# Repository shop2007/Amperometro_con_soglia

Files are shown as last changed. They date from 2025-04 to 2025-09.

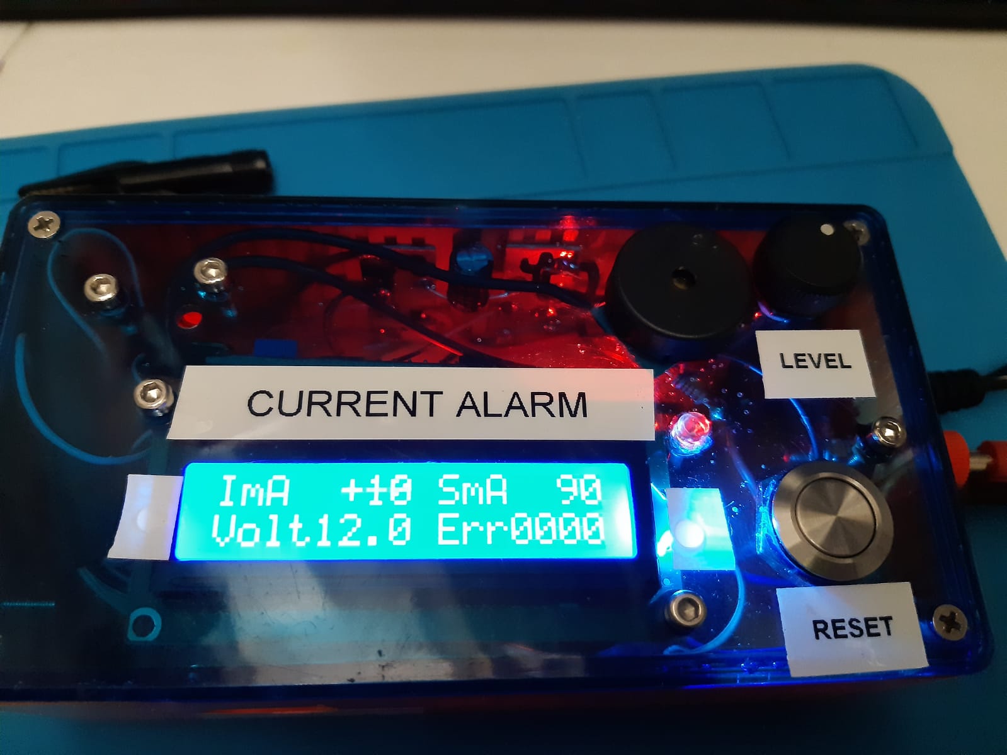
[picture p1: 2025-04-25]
test.jpg

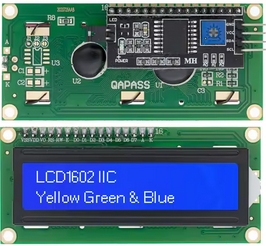
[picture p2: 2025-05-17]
kicad/img/display.jpg

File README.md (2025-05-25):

# Amperometro_con_soglia
Un amperometro galvanicamente isolato con sensore di corrente LEM. Misura la corrente a riposo della batteria auto nel range +/- 1 ampere. Se la corrente supera una soglia impostabile suona il cicalino. Nato per un elettrauto: certe auto moderne si connettono al service a nostra insaputa, e ti trovi la batteria misteriosamente a zero senza saperlo.

# Camper Energy Saver

**Camper Energy Saver** è un sistema elettronico pensato per ottimizzare l'uso dell'energia elettrica a bordo di un camper. Il progetto permette di monitorare in tempo reale corrente e tensione della batteria, proteggere i carichi in caso di sovracorrente, inviare notifiche via SMS e testare l’impianto tramite un menù guidato.

---

## ⚙️ Funzionalità principali

- Lettura di corrente e tensione con sensore LEM
- Gestione soglia corrente per protezione sovraccarichi
- Controllo automatico di un relè di scollegamento carico
- Display LCD I2C 16x2 per visualizzazione locale
- Integrazione con modulo GSM SIM800 per comandi e notifiche SMS
- Comandi remoti: stato, reset, attivazione test, gestione rubrica
- Menu di collaudo guidato (test 1.A, 1.B ecc.)
- Dati persistenti su EEPROM (rubrica, soglie, contatori)
- Watchdog per sicurezza operativa

---

## 🧰 Componenti hardware richiesti

- **Arduino Uno / Nano (ATmega328)**
- **Sensore di corrente LEM** (es. HASS50)
- **Modulo SIM800L GSM**
- **Display LCD 16x2 con interfaccia I2C**
- **Relè 5V**
- **Trimmer** per lettura tensione batteria
- **Resistenze di pull-up/pull-down** dove richiesto
- **Eventuale pulsante** per menu manuale/test
- **Alimentazione 12V camper**

---

## 🖼️ Schema elettrico

<p align="center">
  Schema elettrico
</p>

*(Assicurati che l'immagine sia presente nella cartella `immagini/` del repository.)*

---

## 📸 Foto prototipo montato

<p align="center">
  Montaggio reale
</p>

---

## 🧪 Menù di test e collaudo

Il sistema include un menù test guidato, accessibile da seriale o via SMS:

- **1.A** – Verifica accensione display
- **1.B** – Verifica lettura corrente
- **1.C** – Verifica tensione batteria
- **2.A** – Test attivazione relè
- **2.B** – Verifica invio SMS test

I comandi disponibili via seriale includono:  
`AVANTI`, `RIPETI`, `SALTA`, `ESEGUI`  
oppure selezione diretta con `1.A`, `2.B`, ecc.

---

## 📱 Comandi SMS

| Comando | Descrizione |
|---|---|
| `STATO` | Ricevi stato attuale (corrente, tensione, ecc.) |
| `RESET` | Azzera i contatori di tempo e corrente |
| `TESTRELE` | Attiva il relè per pochi secondi per test |
| `PIN1234` | Autenticazione (sostituire 1234 con il PIN impostato) |
| `HELP` | Elenco comandi disponibili |
| `AGGIUNGI +39xxxxxx`| Aggiunge numero alla rubrica (solo admin) |

---

## 🔧 Installazione

1. **Clona il progetto**:
   ```bash
   git clone https://github.com/shop2007/Camper_energy_saver.git

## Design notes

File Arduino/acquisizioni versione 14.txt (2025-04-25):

Cattura ADC con alimentatore 12 inserito

Corrente nulla nell'anello
Pot A7 = 39 0x27 | Current A2 = 511 0x1FF | Voltage A3 = 0 0x0
Pot A7 = 38 0x26 | Current A2 = 510 0x1FE | Voltage A3 = 0 0x0
Pot A7 = 38 0x26 | Current A2 = 509 0x1FD | Voltage A3 = 0 0x0
Pot A7 = 39 0x27 | Current A2 = 510 0x1FE | Voltage A3 = 0 0x0
Pot A7 = 38 0x26 | Current A2 = 514 0x202 | Voltage A3 = 0 0x0
Pot A7 = 38 0x26 | Current A2 = 512 0x200 | Voltage A3 = 0 0x0
Pot A7 = 38 0x26 | Current A2 = 515 0x203 | Voltage A3 = 0 0x0
Pot A7 = 39 0x27 | Current A2 = 507 0x1FB | Voltage A3 = 0 0x0
Pot A7 = 39 0x27 | Current A2 = 510 0x1FE | Voltage A3 = 0 0x0
Pot A7 = 38 0x26 | Current A2 = 512 0x200 | Voltage A3 = 0 0x0
Pot A7 = 39 0x27 | Current A2 = 511 0x1FF | Voltage A3 = 0 0x0
Pot A7 = 38 0x26 | Current A2 = 511 0x1FF | Voltage A3 = 0 0x0
Pot A7 = 39 0x27 | Current A2 = 514 0x202 | Voltage A3 = 0 0x0
Pot A7 = 39 0x27 | Current A2 = 513 0x201 | Voltage A3 = 0 0x0
Pot A7 = 39 0x27 | Current A2 = 511 0x1FF | Voltage A3 = 0 0x0
Pot A7 = 38 0x26 | Current A2 = 512 0x200 | Voltage A3 = 0 0x0
Pot A7 = 39 0x27 | Current A2 = 515 0x203 | Voltage A3 = 0 0x0
Pot A7 = 39 0x27 | Current A2 = 513 0x201 | Voltage A3 = 0 0x0
Pot A7 = 39 0x27 | Current A2 = 510 0x1FE | Voltage A3 = 0 0x0
Pot A7 = 38 0x26 | Current A2 = 512 0x200 | Voltage A3 = 0 0x0
Pot A7 = 38 0x26 | Current A2 = 511 0x1FF | Voltage A3 = 0 0x0

0,42A 
Pot A7 = 39 0x27 | Current A2 = 615 0x267 | Voltage A3 = 0 0x0
Pot A7 = 39 0x27 | Current A2 = 618 0x26A | Voltage A3 = 0 0x0
Pot A7 = 39 0x27 | Current A2 = 617 0x269 | Voltage A3 = 0 0x0

-0,40A
Pot A7 = 39 0x27 | Current A2 = 409 0x199 | Voltage A3 = 0 0x0
Pot A7 = 38 0x26 | Current A2 = 410 0x19A | Voltage A3 = 0 0x0
Pot A7 = 39 0x27 | Current A2 = 407 0x197 | Voltage A3 = 0 0x0

Volmetro

5,05v  
Pot A7 = 38 0x26 | Current A2 = 513 0x201 | Voltage A3 = 211 0xD3
Pot A7 = 39 0x27 | Current A2 = 509 0x1FD | Voltage A3 = 211 0xD3
Pot A7 = 38 0x26 | Current A2 = 511 0x1FF | Voltage A3 = 211 0xD3

8,94 v
Pot A7 = 38 0x26 | Current A2 = 512 0x200 | Voltage A3 = 392 0x188
Pot A7 = 38 0x26 | Current A2 = 512 0x200 | Voltage A3 = 392 0x188
Pot A7 = 38 0x26 | Current A2 = 511 0x1FF | Voltage A3 = 392 0x188

12.00v
Pot A7 = 38 0x26 | Current A2 = 510 0x1FE | Voltage A3 = 535 0x217
Pot A7 = 38 0x26 | Current A2 = 510 0x1FE | Voltage A3 = 535 0x217
Pot A7 = 38 0x26 | Current A2 = 515 0x203 | Voltage A3 = 535 0x217

15.65v
Pot A7 = 38 0x26 | Current A2 = 512 0x200 | Voltage A3 = 705 0x2C1
Pot A7 = 39 0x27 | Current A2 = 510 0x1FE | Voltage A3 = 705 0x2C1
Pot A7 = 38 0x26 | Current A2 = 509 0x1FD | Voltage A3 = 705 0x2C1

chatgpt
Un adc a 10 bit di arduino nano + rete di attenuazione restituisce i seguenti valori
A 5,05v -> 211 bit (0xD3)
A 8,94v -> 392 bit (0x188)
A 12.00v -> 535 bit (0x217)
A 15.65v -> 705 bit (0x2C1)

Vorrei mi disegnassi una curva teorica del funzionamento, volt-bit

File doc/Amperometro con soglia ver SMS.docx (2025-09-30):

Amperometro con soglia ed allarme sonoro/luminoso/contatto

Versione SMS

V3 30/09/2025

Note importanti:

NON CONNETTERE O DISCONNETTERE IL MODULO SIM CON ALIMENTAZIONE INSERITA. PERICOLO DI DANNEGGIAMENTO DELLA SCHEDA SIM

SE SI ALIMENTA CON BATTERIA ASSICURARE BUON CONTATTO CON I POLI PRIMA DI INSERIRE IL JACK. EVITARE CONTATTI INCERTI. PERICOLO DANNEGGIAMENTO DELLA SCHEDA SIM

MESSA IN FUNZIONE E USO DELLA PARTE SMS.

Firmware installato: GIT\Amperometro_con_soglia\Arduino\amp_sog_19_sms10

- All'avvio il led bianco lampeggia alcune volte velocemente in attesa della SIM.
- Mentre la sim tenta di connettersi alla rete cellulare il suo led rosso e lampeggia velocemente.
- Quando è connessa lampeggia una volta ogni tre secondi.
- Quando manda un sms o lo riceve, accende il led bianco

Comandi da inviare via SMS da qualsiasi telefono (attenzione alle Maiuscole-Minuscole).

- “User1 +393332108888” - mette il numero ricevuto come utente 1 da avvisare su allarmi Aggiungere ai numeri il +39 . User1 riceve SMS di risposta "Utente1 registrato correttamente"
- “User2 +393332109999” - mette il numero ricevuto come utente 2 da avvisare su allarmi Aggiungere ai numeri il +39 . User2 riceve SMS di risposta "Utente2 registrato correttamente"
- Statoattuale - Riceve un SMS con i valori sul display in quel momento
- Resetsystem - resetta da remoto il sistema e il conta allarmi
- DeleteUtente2 - resta attivo solo “User1”, che riceve SMS di risposta "Utente 2 cancellato"

Se la sim è connessa blinka ogni 3 secondi, anche se non c’è credito o sms disponibili

In caso di allarme per soglia superata verrà inviato solo il primo SMS.

Se si stacca l’interruttore della SIM, quando si riconnette occorre premere il tasto RESET per essere sicuri che la SIM si ricolleghi correttamente (verificare lampeggio ogni 3 secondi)

Caratteristiche del sensore LEM.

- Corrente (cavo passante nell’anello)
  - Range +/- 1500 mA DC (corrente continua)
  - Risoluzione +/-4 mA (LSB dell’ADC a 10 bit di Arduino)
  - Precisione 3%
- Tensione di batteria, Banana rossa (+) e Nera (-)
  - Range da 3 a 22 Volt DC
  - Risoluzione 0.1 Volt
  - Precisione +/- 0.1 Volt
- Soglia Allarme sonoro (potenziometro)
  - Range da 1 a 1000 mA
  - Vale per entrambe le polarità della corrente
- Conteggio superamento soglia di corrente
  - Range da 1 a 9999 secondi
  - Precisione 1mA
  - Resettabile continuamente con pulsante
- Allarmi soglia superata
  - Visivo (Led bianco)
  - Acustico (Cicalino, escludibile se al reset si tiene premuto il pulsante di azzeramento per alcuni secondi)
  - Uscita relay (su mammut), contatto chiuso per soglia superata

Note:

- Scritte su display:
  - Ima +18 = corrente in mA letta dal sensore ad anello, bipolare con segno
  - SmA 912 = Soglia in mA del livello da superare per avere allarme
  - Volt 11.9 = tensione rilevata sulle banane rossa/nera – Unipolare senza segno
  - Err 0000 = conteggio secondi in cui la corrente ha superato la soglia
- LEVEL = potenziometro per regolare la soglia SmA
- RESET = pulsante di azzeramento conteggio secondi superamento soglia
- LED BIANCO = segnala soglia superata

Alimentare con alimentatore esterno 12v

La presa USB C serve solo per aggiornamento firmware

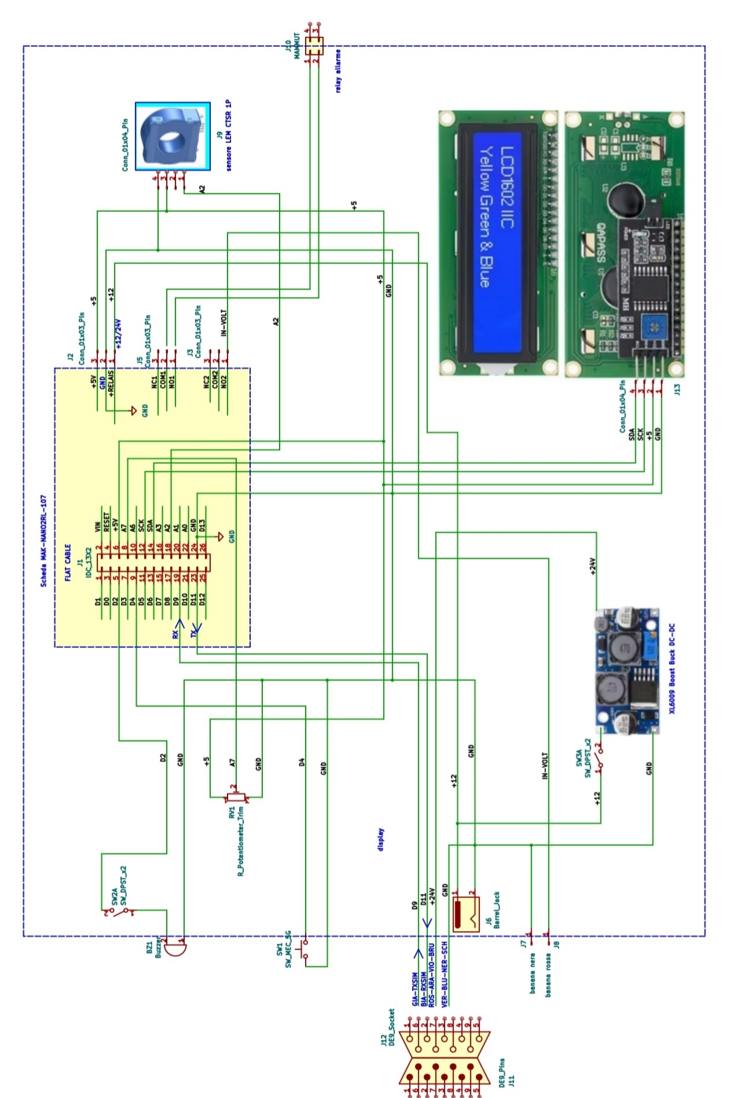
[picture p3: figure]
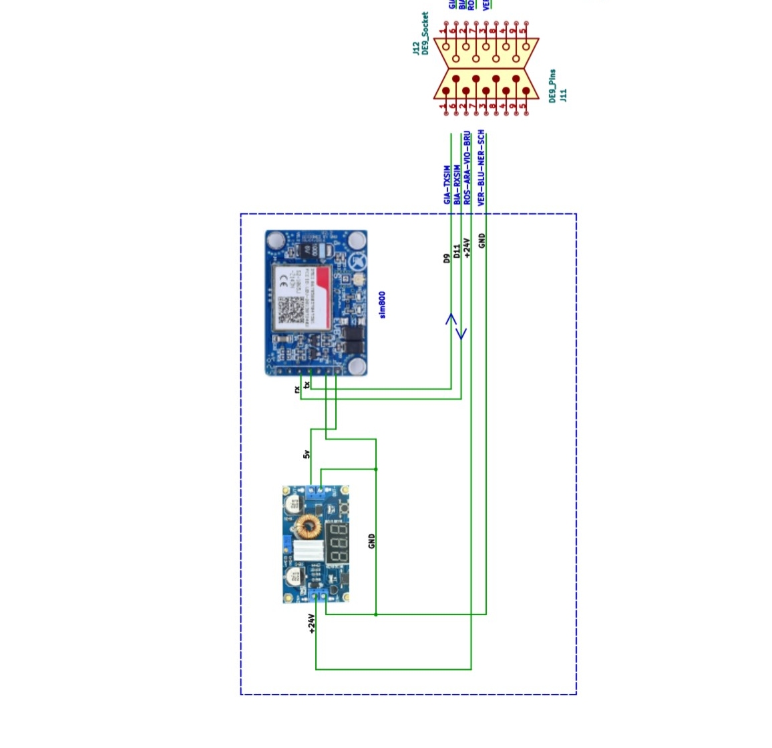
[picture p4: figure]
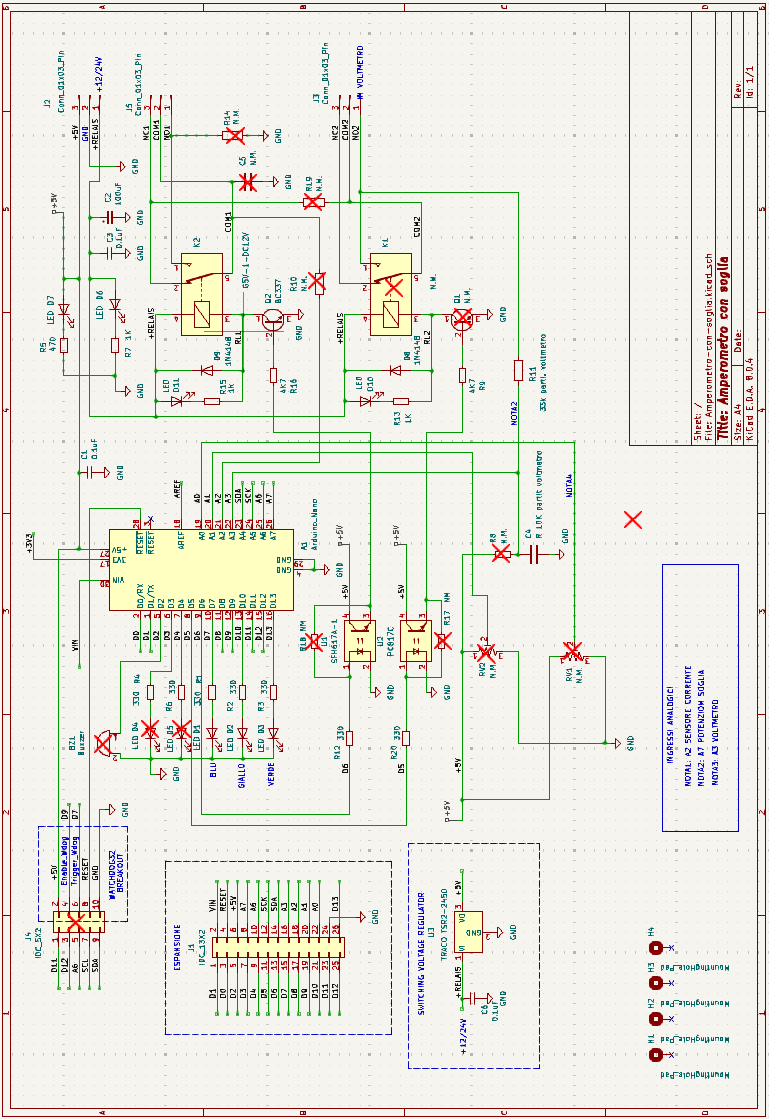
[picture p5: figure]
Immagine che contiene testo, diagramma, Piano, schematico Il contenuto generato dall'IA potrebbe non essere corretto.

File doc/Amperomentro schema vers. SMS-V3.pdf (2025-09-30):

# Amperometro con soglia ed allarme sonoro/luminoso/contatto Versione SMS

V3 30/09/2025

# Note importanti: NON CONNETTERE O DISCONNETTERE IL MODULO SIM CON ALIMENTAZIONE INSERITA. PERICOLO DI DANNEGGIAMENTO DELLA SCHEDA SIM SE SI ALIMENTA CON BATTERIA ASSICURARE BUON CONTATTO CON I POLI PRIMA DI INSERIRE IL JACK. EVITARE CONTATTI INCERTI. PERICOLO DANNEGGIAMENTO DELLA SCHEDA SIM

MESSA IN FUNZIONE E USO DELLA PARTE SMS.
Firmware installato: GIT\Amperometro_con_soglia\Arduino\amp_sog_19_sms10
- All'avvio il led bianco lampeggia alcune volte velocemente in attesa della SIM.
- Mentre la sim tenta di connettersi alla rete cellulare il suo led rosso e lampeggia velocemente.
- Quando è connessa lampeggia una volta ogni tre secondi.
- Quando manda un sms o lo riceve, accende il led bianco

Comandi da inviare via SMS da qualsiasi telefono (attenzione alle Maiuscole-Minuscole).
- “User1 +393332108888” - mette il numero ricevuto come utente 1 da avvisare su allarmi Aggiungere ai numeri il +39 . User1 riceve SMS di risposta "Utente1 registrato correttamente"
- “User2 +393332109999” - mette il numero ricevuto come utente 2 da avvisare su allarmi Aggiungere ai numeri il +39 . User2 riceve SMS di risposta "Utente2 registrato correttamente"
- Statoattuale - Riceve un SMS con i valori sul display in quel momento
- Resetsystem - resetta da remoto il sistema e il conta allarmi
- DeleteUtente2 - resta attivo solo “User1”, che riceve SMS di risposta "Utente 2 cancellato"

Se la sim è connessa blinka ogni 3 secondi, anche se non c’è credito o sms disponibili
In caso di allarme per soglia superata verrà inviato solo il primo SMS.
Se si stacca l’interruttore della SIM, quando si riconnette occorre premere il tasto RESET per essere sicuri che la SIM si ricolleghi correttamente (verificare lampeggio ogni 3 secondi)

Caratteristiche del sensore LEM.
- Corrente (cavo passante nell’anello)
o Range +/- 1500 mA DC (corrente continua)
o Risoluzione +/-4 mA (LSB dell’ADC a 10 bit di Arduino) o Precisione 3%
- Tensione di batteria, Banana rossa (+) e Nera (-)
o Range da 3 a 22 Volt DC
o Risoluzione 0.1 Volt
o Precisione +/- 0.1 Volt
- Soglia Allarme sonoro (potenziometro)
o Range da 1 a 1000 mA
o Vale per entrambe le polarità della corrente
- Conteggio superamento soglia di corrente
o Range da 1 a 9999 secondi
o Precisione 1mA
o Resettabile continuamente con pulsante
- Allarmi soglia superata
o Visivo (Led bianco)
o Acustico (Cicalino, escludibile se al reset si tiene premuto il pulsante di azzeramento per alcuni secondi)
o Uscita relay (su mammut), contatto chiuso per soglia superata

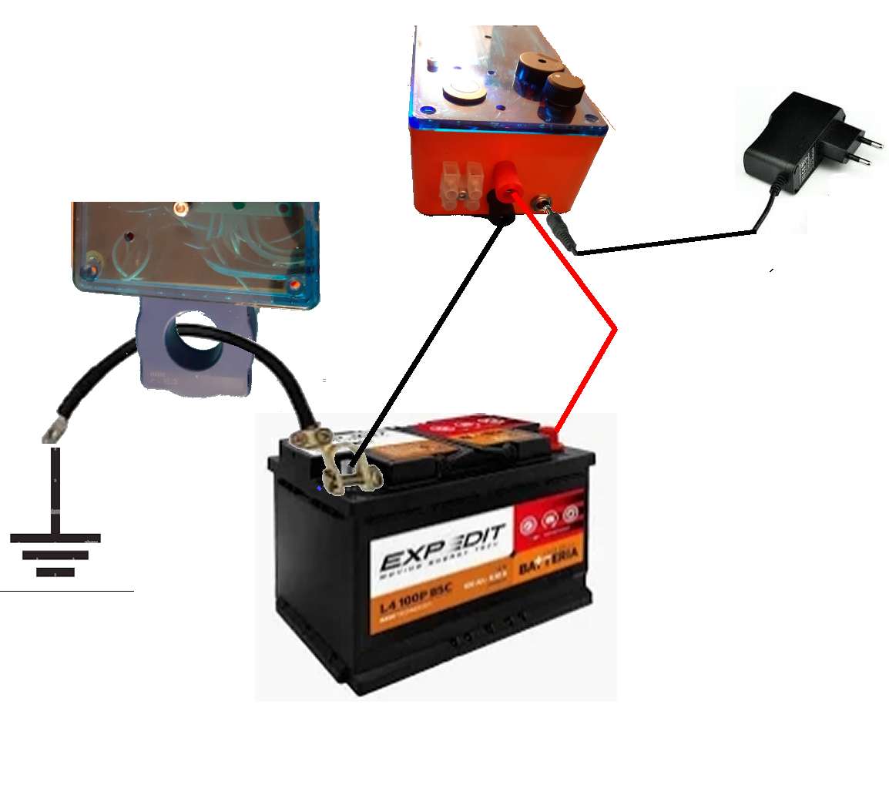
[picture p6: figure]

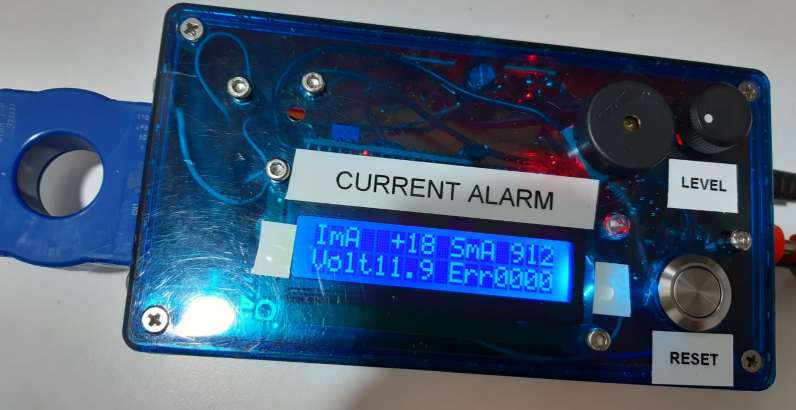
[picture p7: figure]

Note:
- Scritte su display:
o Ima +18 = corrente in mA letta dal sensore ad anello, bipolare con segno
o SmA 912 = Soglia in mA del livello da superare per avere allarme
o Volt 11.9 = tensione rilevata sulle banane rossa/nera – Unipolare senza segno o Err 0000 = conteggio secondi in cui la corrente ha superato la soglia
- LEVEL = potenziometro per regolare la soglia SmA
- RESET = pulsante di azzeramento conteggio secondi superamento soglia
- LED BIANCO = segnala soglia superata

Alimentare con alimentatore esterno 12v
La presa USB C serve solo per aggiornamento firmware


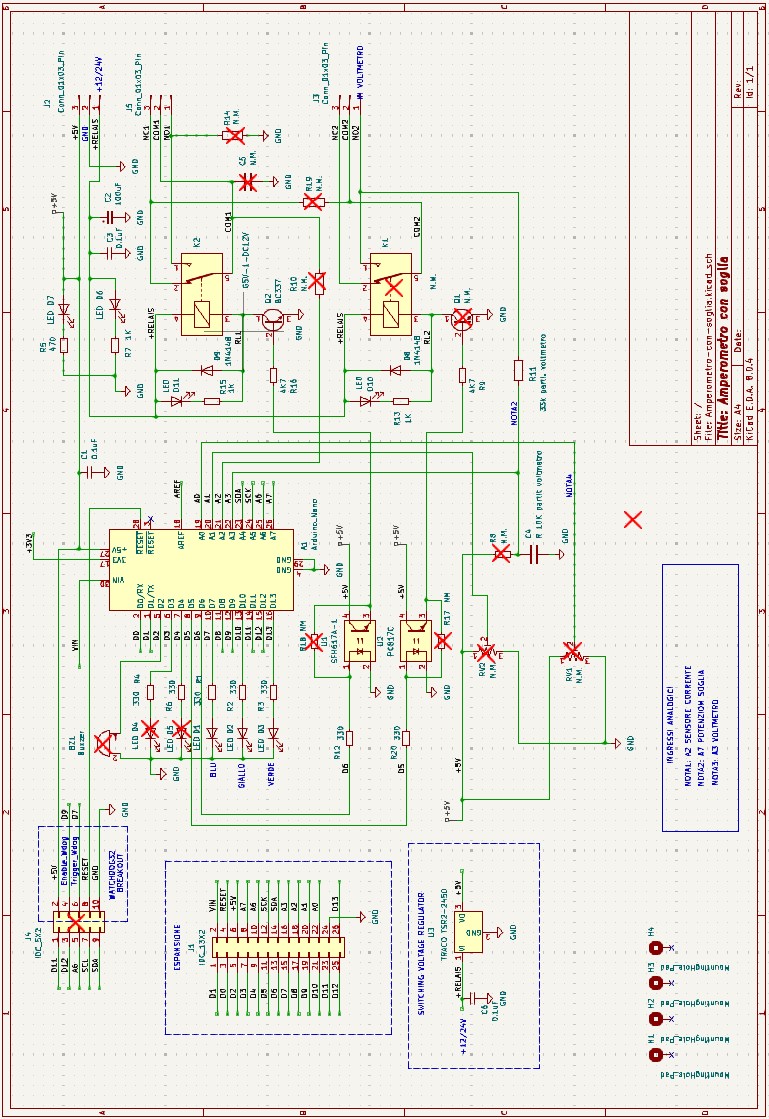
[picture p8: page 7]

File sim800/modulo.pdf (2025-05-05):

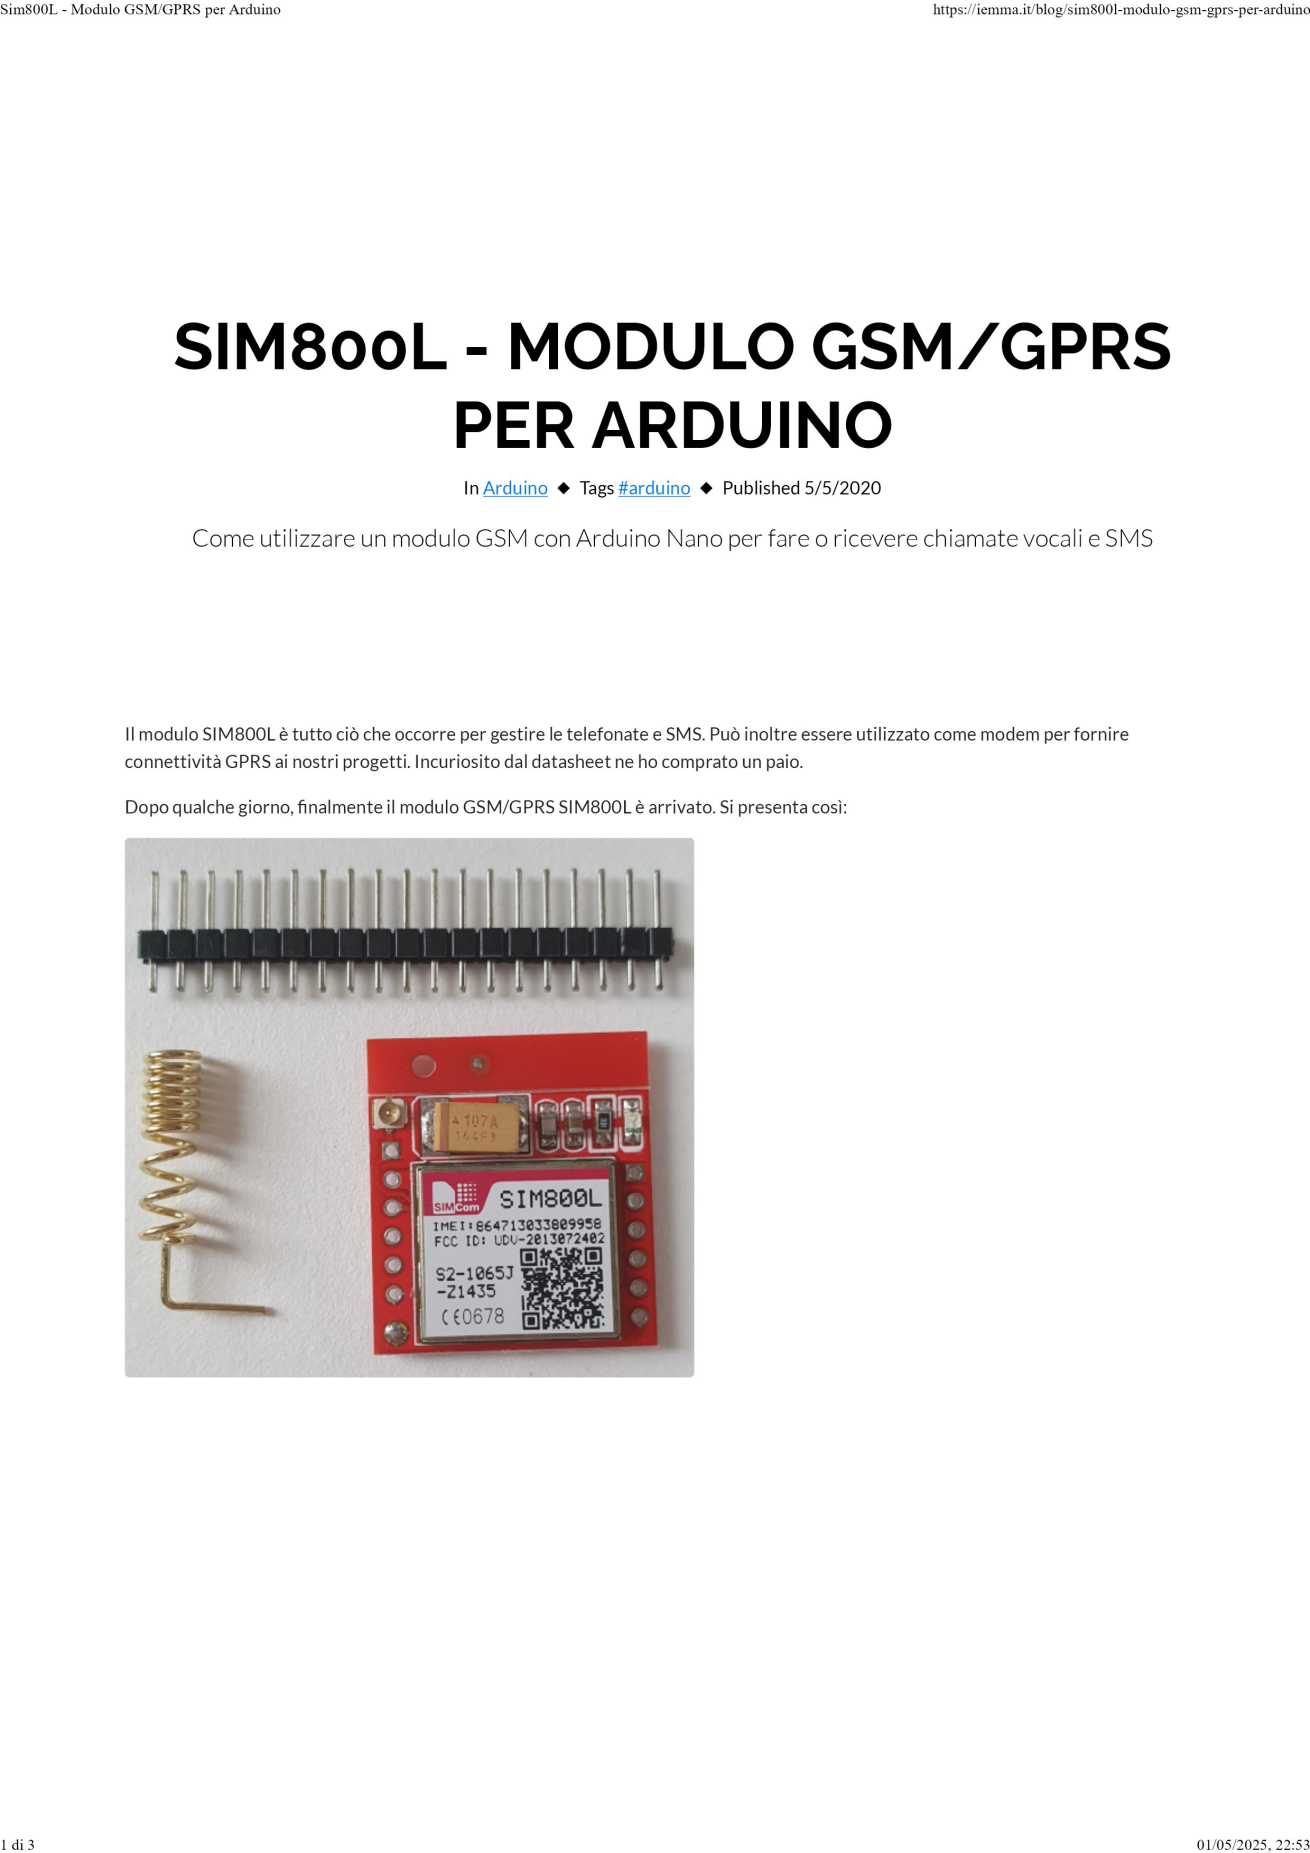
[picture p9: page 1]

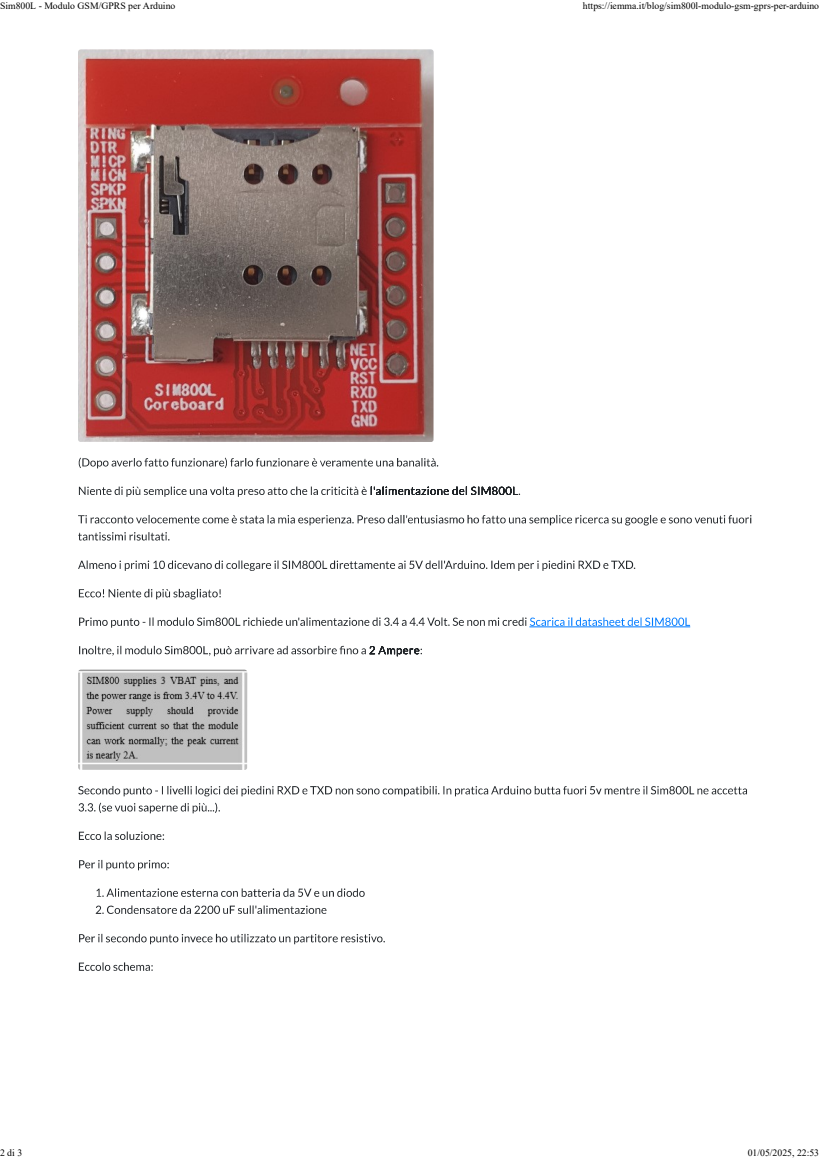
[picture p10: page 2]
Sim800L - Modulo GSM/GPRS per Arduino; https://iemma.it/blog/sim800l-modulo-gsm-gprs-per-arduino

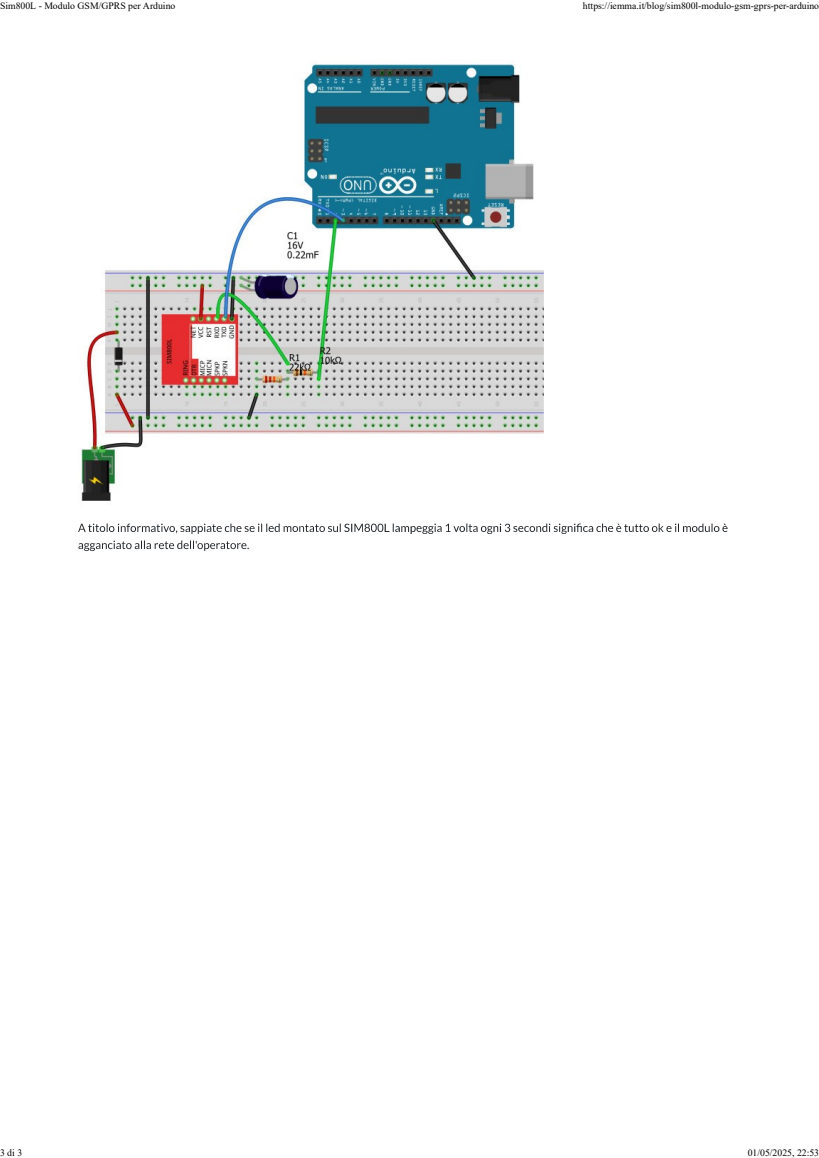
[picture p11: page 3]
Sim800L - Modulo GSM/GPRS per Arduino; https://iemma.it/blog/sim800l-modulo-gsm-gprs-per-arduino

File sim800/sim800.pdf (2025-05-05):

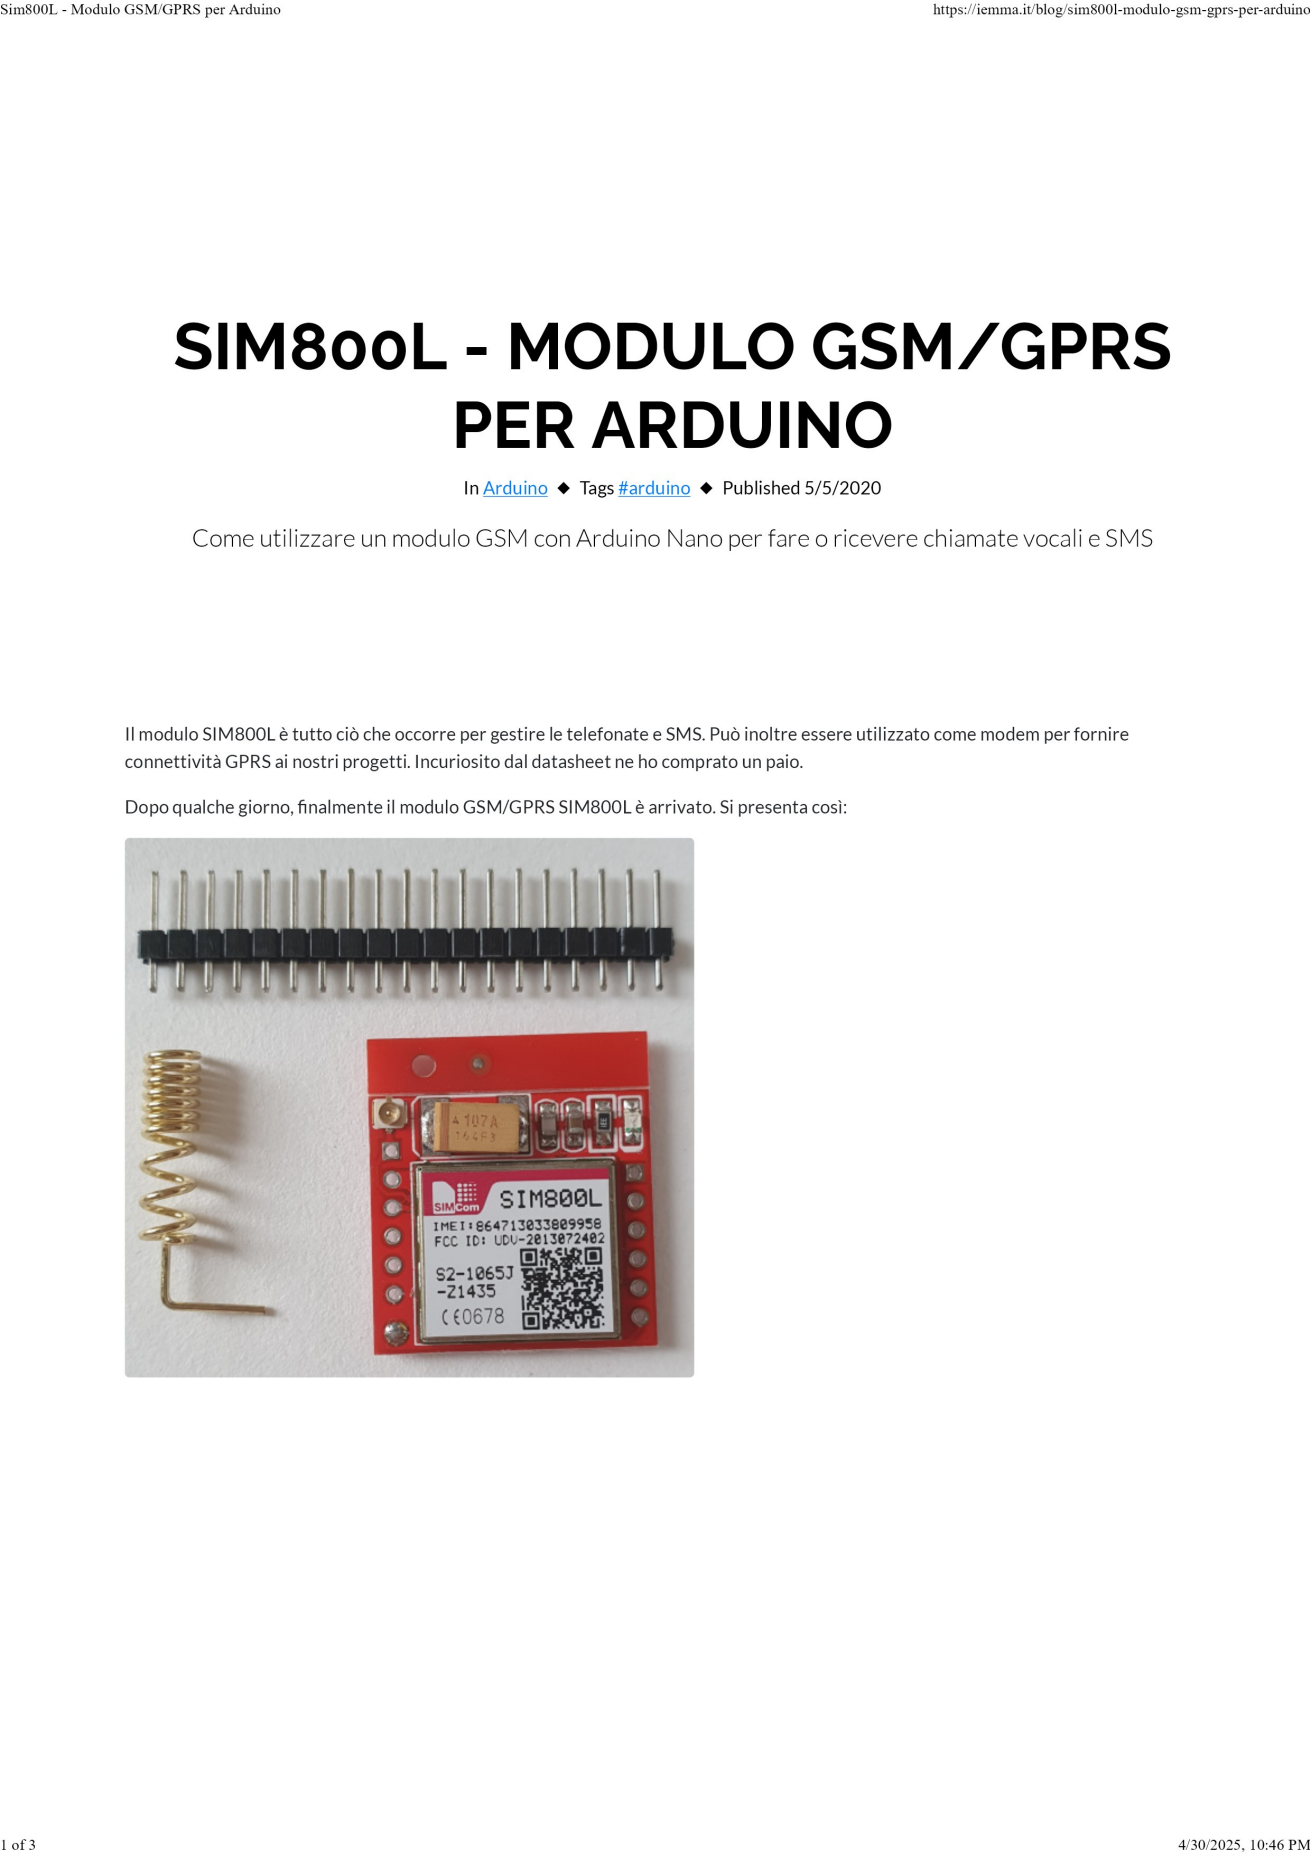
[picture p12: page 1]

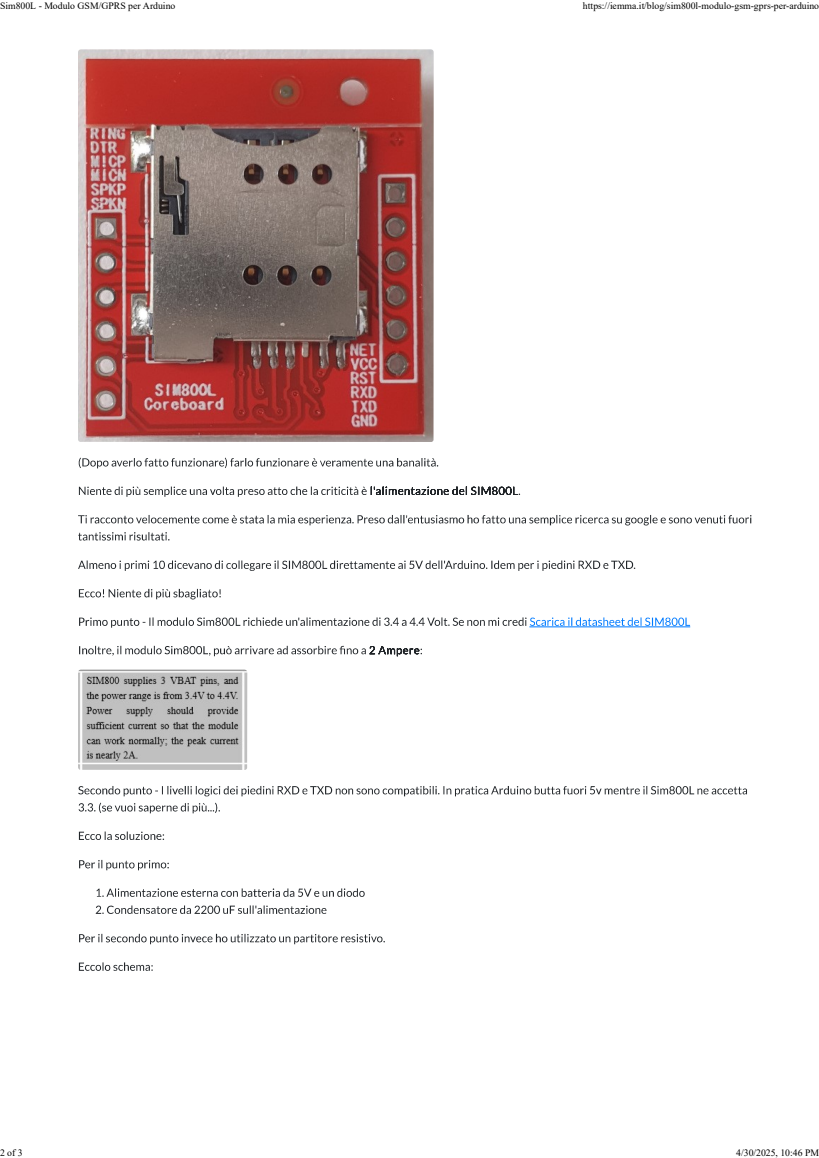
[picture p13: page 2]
Sim800L - Modulo GSM/GPRS per Arduino; https://iemma.it/blog/sim800l-modulo-gsm-gprs-per-arduino

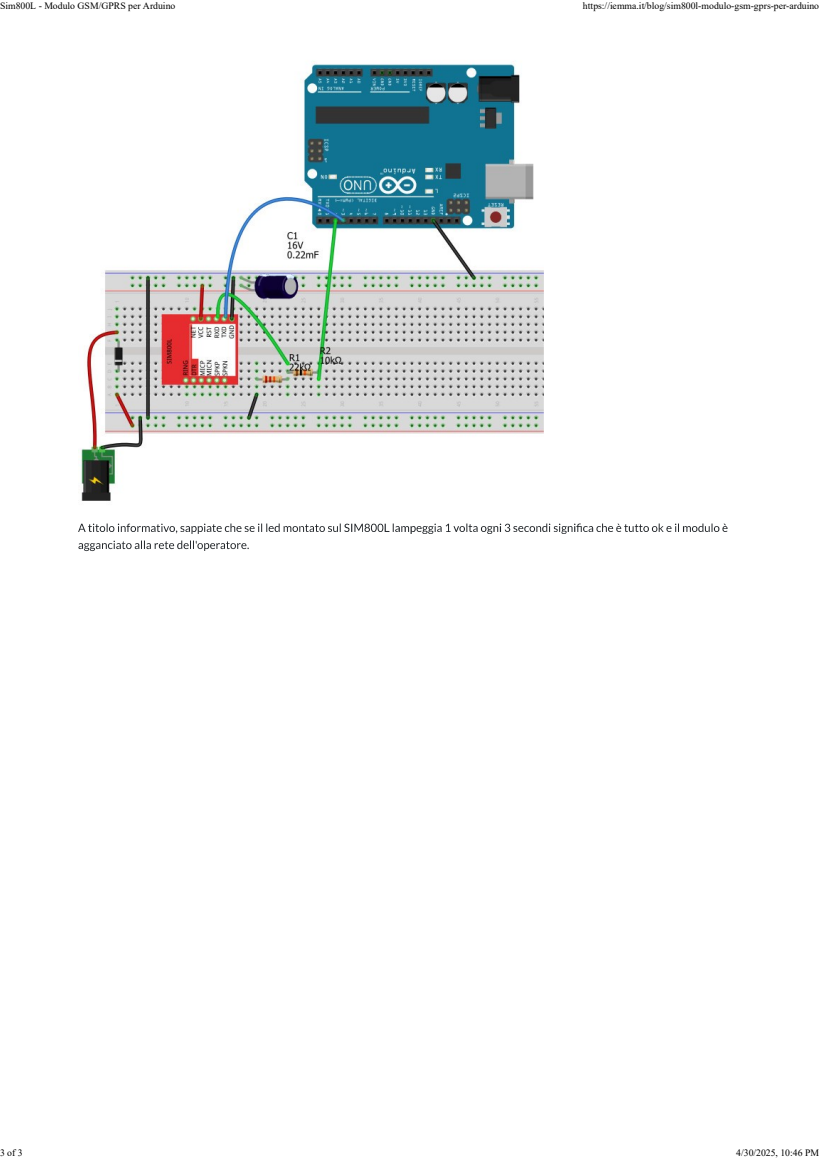
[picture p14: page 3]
Sim800L - Modulo GSM/GPRS per Arduino; https://iemma.it/blog/sim800l-modulo-gsm-gprs-per-arduino

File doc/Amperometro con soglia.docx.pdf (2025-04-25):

# Amperometro con soglia ed allarme sonoro/luminoso/contatto

V1 19/02/2025
Caratteristiche.
- Corrente (cavo passante nell’anello)
o Range +/- 1500 mA DC (corrente continua)
o Risoluzione +/-4 mA (LSB dell’ADC a 10 bit di Arduino) o Precisione 3%
- Tensione di batteria, Banana rossa (+) e Nera (-)
o Range da 3 a 22 Volt DC
o Risoluzione 0.1 Volt
o Precisione +/- 0.1 Volt
- Soglia Allarme sonoro (potenziometro)
o Range da 1 a 1000 mA
o Vale per entrambe le polarità della corrente
- Conteggio superamento soglia di corrente
o Range da 1 a 9999 secondi
o Precisione 1mA
o Resettabile continuamente con pulsante
- Allarmi soglia superata
o Visivo (Led bianco)
o Acustico (Cicalino, escludibile se al reset si tiene premuto il pulsante di azzeramento per alcuni secondi)
o Uscita relay (su mammut), contatto chiuso per soglia superata

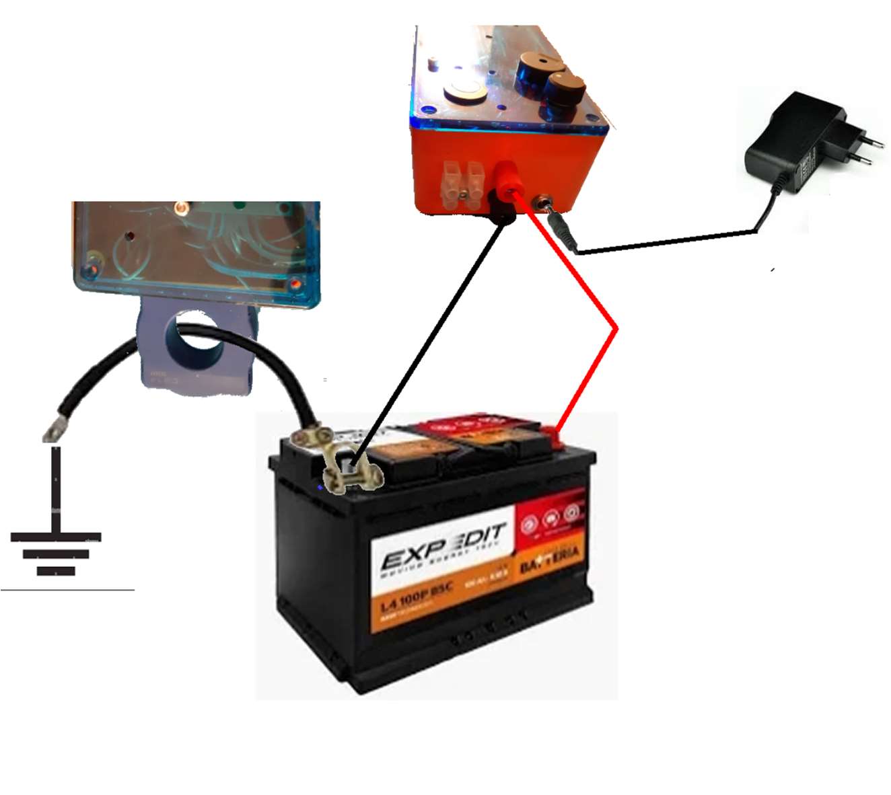
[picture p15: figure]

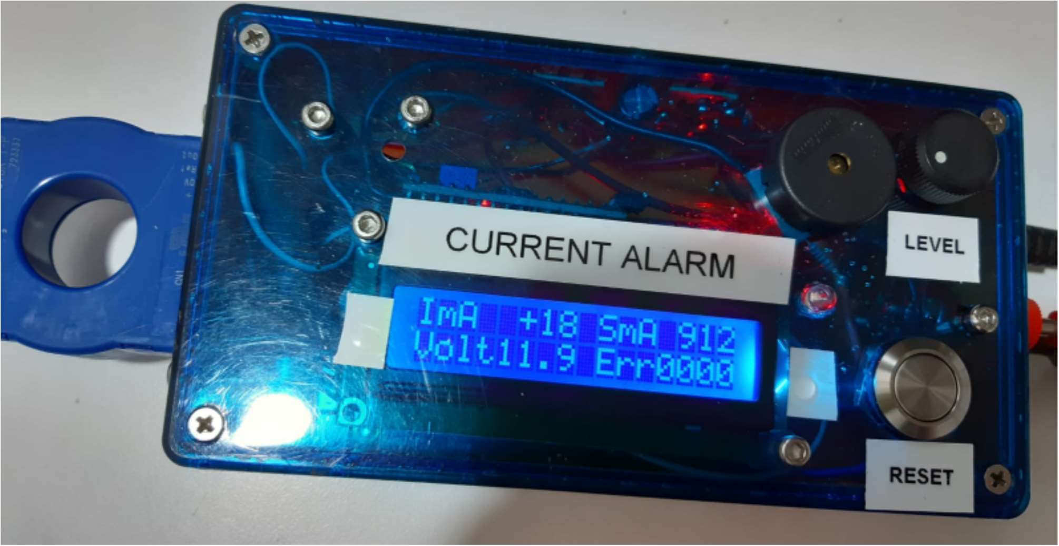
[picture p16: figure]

Note:
- Scritte su display:
o Ima +18 = corrente in mA letta dal sensore ad anello, bipolare con segno
o SmA 912 = Soglia in mA del livello da superare per avere allarme
o Volt 11.9 = tensione rilevata sulle banane rossa/nera – Unipolare senza segno o Err 0000 = conteggio secondi in cui la corrente ha superato la soglia
- LEVEL = potenziometro per regolare la soglia SmA
- RESET = pulsante di azzeramento conteggio secondi superamento soglia
- LED BIANCO = segnala soglia superata
Alimentare con alimentatore esterno 12v
La presa USB C serve solo per aggiornamento firmware

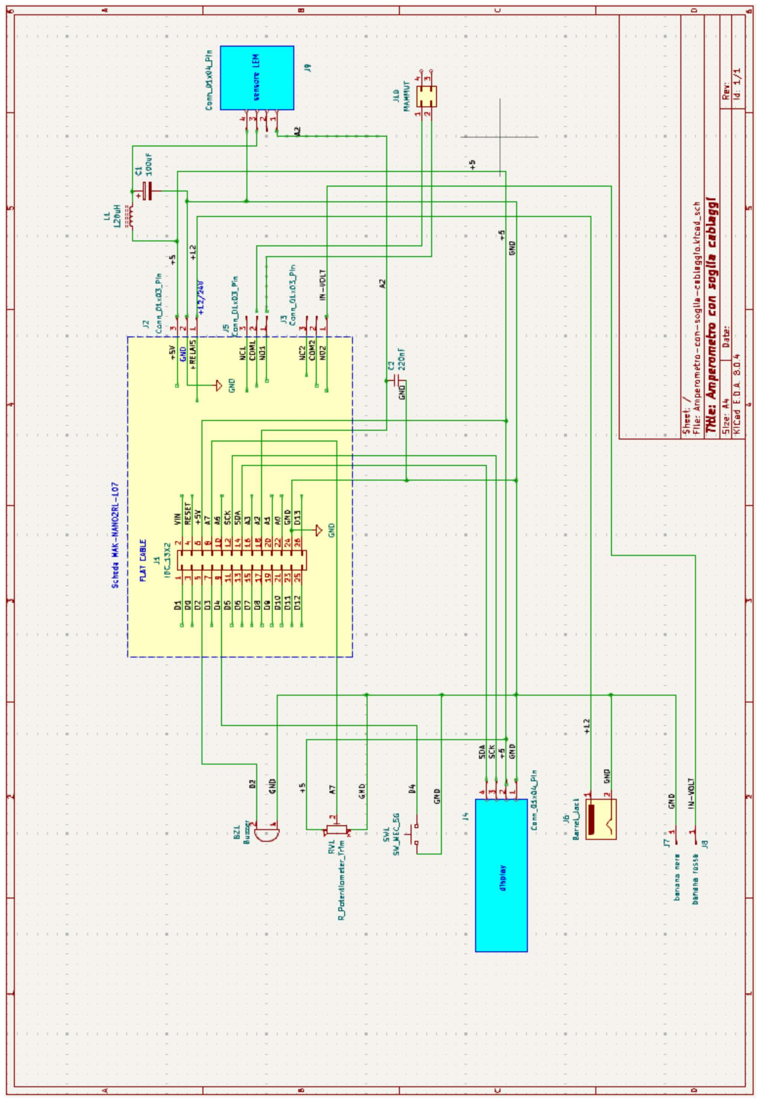
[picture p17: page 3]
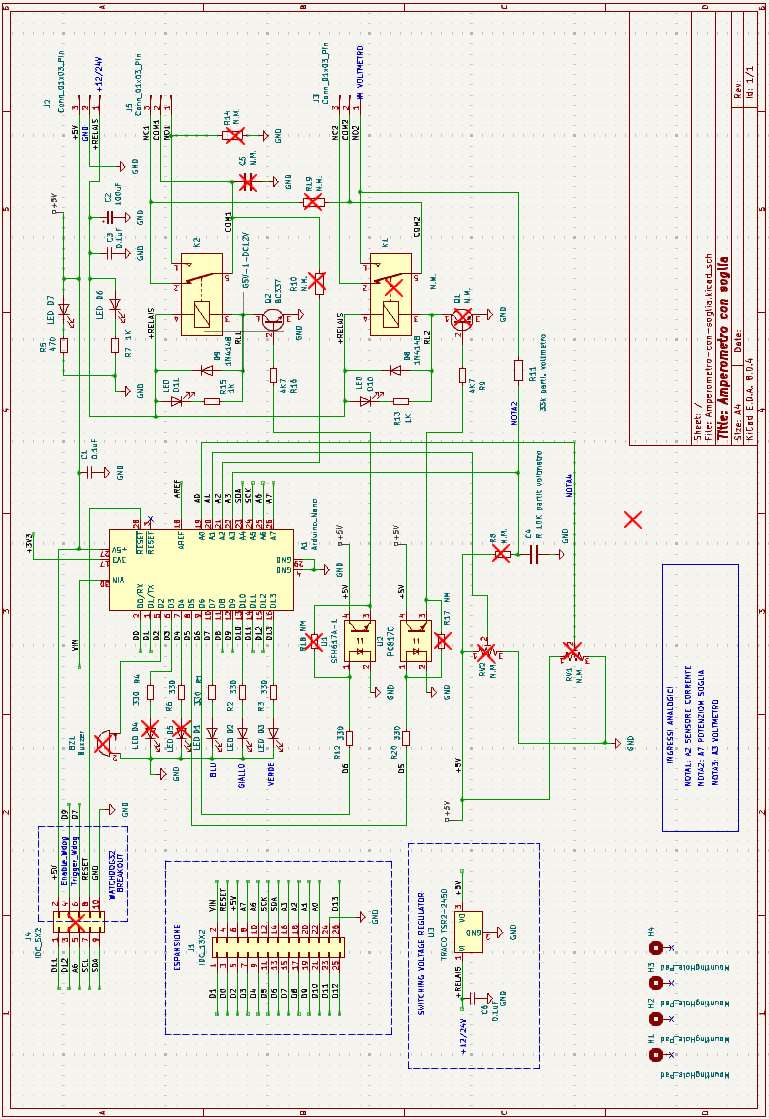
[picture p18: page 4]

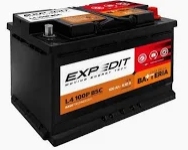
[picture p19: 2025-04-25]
doc/pic/batt1.jpg

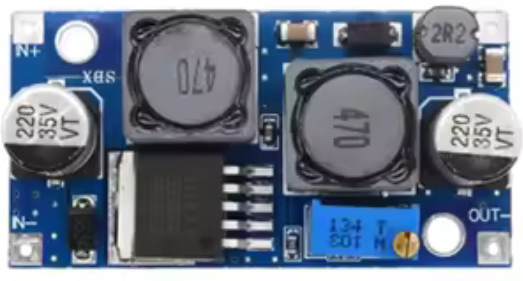
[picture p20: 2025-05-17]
kicad/img/XL6009.png

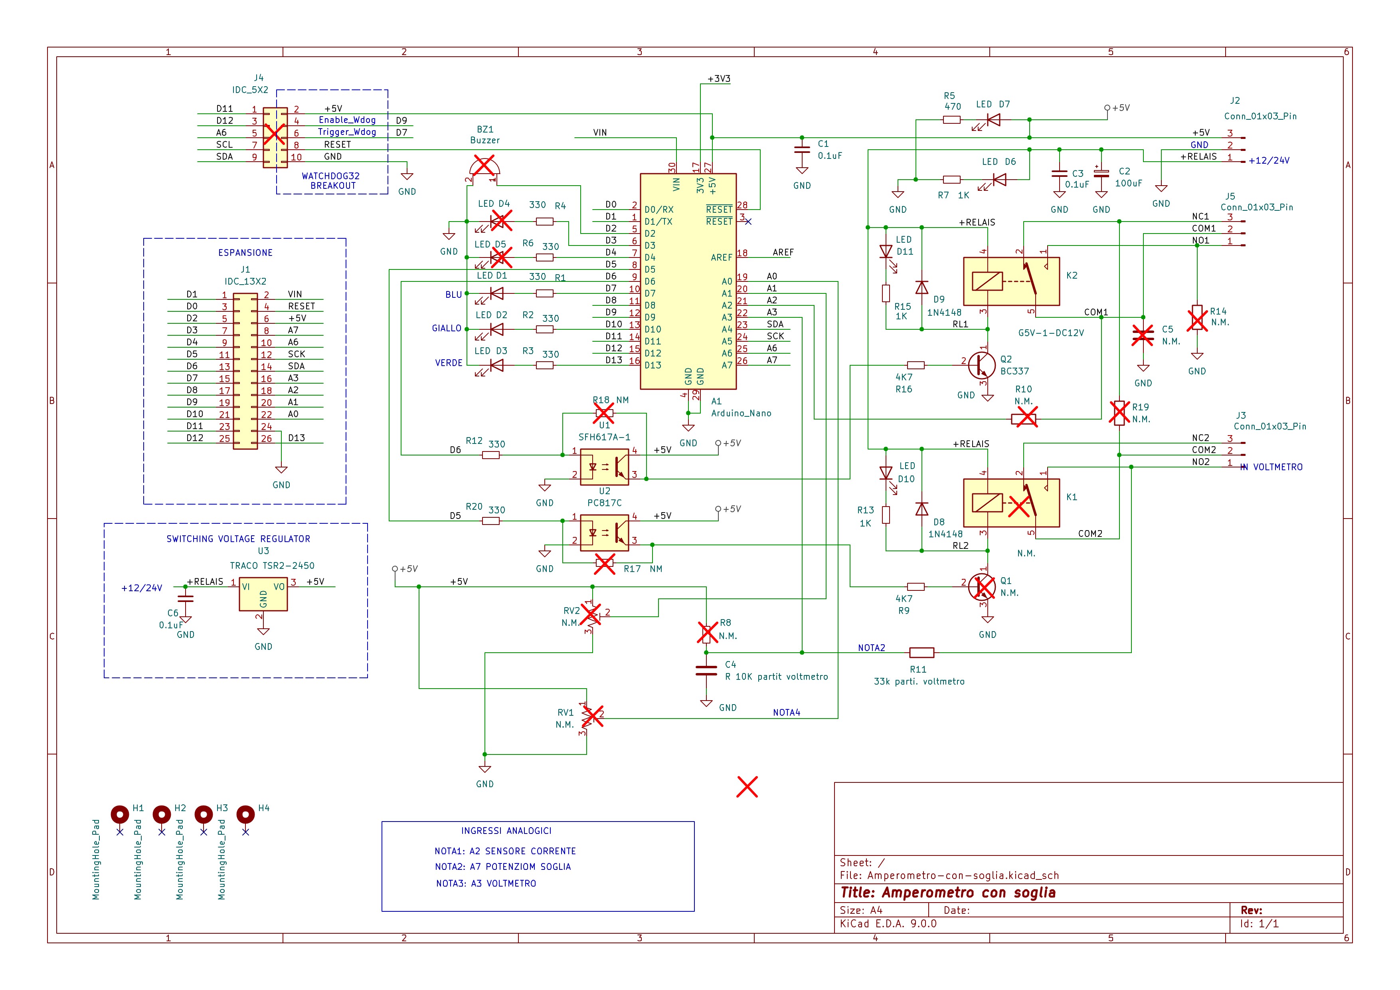
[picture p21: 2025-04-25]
doc/pic/schema01.jpg

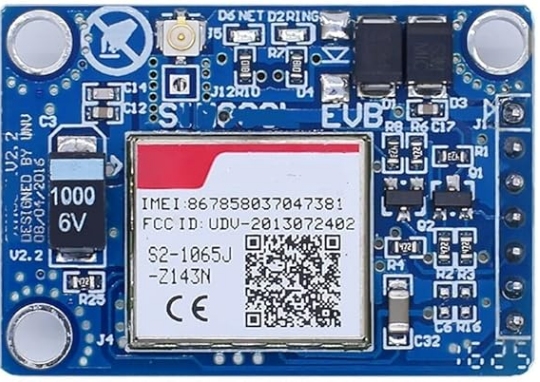
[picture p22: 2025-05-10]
sim800.jpg

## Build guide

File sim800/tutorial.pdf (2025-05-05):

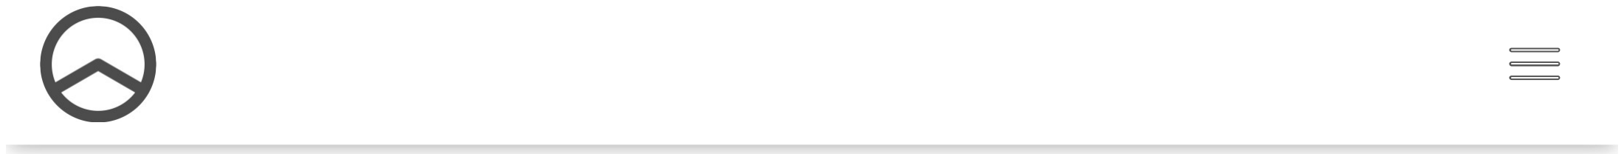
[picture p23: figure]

## Guida completa modulo GSM SIM800L

Pubblicato da Alessandro il 02/01/2023

# Introduzione

Confesso che non è la prima volta che progetto un dispositivo che integra questo modulo di comunicazione GSM. Tuttavia, in passato, mi sono sempre arenato senza riuscire a farlo funzionare.

Stavolta ho passato molte ore a studiare e a fare prove fino a quando non ho finalmente ottenuto il risultato sperato. Dalla lettura dei forum ho notato che non poche persone hanno avuto i miei stessi problemi. Ecco perché ho deciso di condividere l’esito delle mie tante ricerche e dei vari esperimenti (molti dei quali falliti).

Spero che questa guida aiuti molti maker appassionati di elettronica a risolvere gli stessi problemi e a realizzare i loro progetti.

Cliccando sul tag SIM800L potrete scoprire tutti gli articoli e i progetti in cui abbiamo utilizzato questo componente.

# Componenti

Guida completa modulo GSM SIM800L - officinasottocasa | https://www.officinasottocasa.it/gsm-sim800l/
1 di 17 | 01/05/2025, 22:47

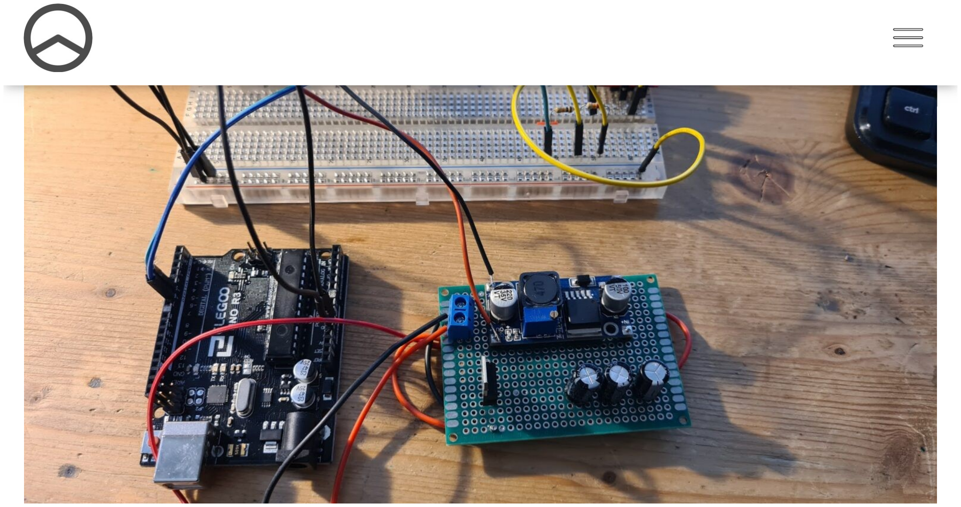
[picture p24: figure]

Iniziamo come sempre nei nostri articoli con il materiale utilizzato nel progetto:

.Una CPU Arduino UNO R3 (versione cinese con interfaccia CH340) per gestire l’interfaccia con il PC: guarda l’articolo su amazon
Uno step-down DC-DC con integrato LM2596: guarda l’articolo su amazon Un modulo GSM SIM800L: guarda l’articolo su amazon
Una resistenza da 10K e una da 22K;
Condensatori vari messi in parallelo.

(In qualità di Affiliato Amazon io ricevo un guadagno dagli acquisti idonei)

# Alimentazione

Iniziamo con una tabella che riporta l’assorbimento (in mA e A) del modulo per ogni specifica

Prototipo con breadbord per SIM800L e UNO R3

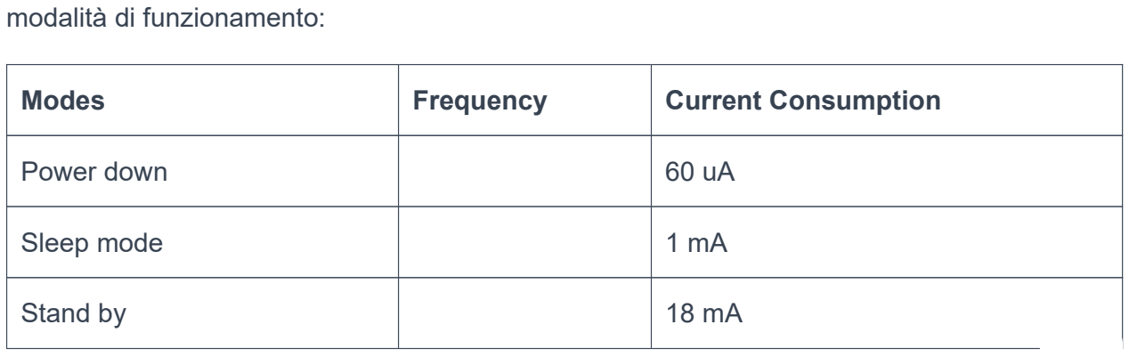
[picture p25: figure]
modalità di funzionamento:; Modes; Frequency; Current Consumption; Power down; Sleep mode; Stand by

2 di 17 | 01/05/2025, 22:47

Call | GSM850 | 199 mA
Call | EGSM900 | 216 mA
Call | DCS1800 | 146 mA
Call | PCS1900 | 131 mA
GPRS | | 453 mA
Transmission burst | | 2 A

Tabella degli assorbimenti per modalità di funzionamento
L’intervallo di tensione per l’alimentazione di questo modulo va dai 3.4V ai 4.4V. Per questo motivo, nel mio precedente articolo sull’allarme GSM per il livello di carica della batteria della moto (https://www.officinasottocasa.it/allarme-gsm-per-batteria-scarica-progettohardware/), avevo pensato di alimentare il modulo con un semplice partitore di tensione in uscita dall’integrato LM7805.

Guardando la tabella della corrente necessaria per il funzionamento delle varie modalità appare evidente che, contrariamente a quanto pensassi (e avessi visto in qualche articolo su internet), non è assolutamente possibile alimentare il modulo in questo modo. Tanto meno utilizzando direttamente la porta 5V di Arduino.

In rete ho visto alcuni “colleghi” che hanno utilizzato una batteria LIPO da 3.7V. Effettivamente sarebbe stato possibile. Ma per l’applicazione in dispositivi permanentemente connessi avremmo dovuto sviluppare anche la gestione della carica della stessa batteria, magari con un BMS per batterie LIPO.

Ho preferito la soluzione dello step-down DC-DC che trova facile impiego sia per applicazione su banco prova che nel mio progetto originario da cui nasce l’esigenza del suo utilizzo.

Visto che tornerà utile spesso, mi sono costruito (su una basetta mille-fori) un mini modulo di alimentazione permanente composto da un banale LM7805 (che, lo ricordiamo, è uno step-down DC-DC con uscita fissa a 5V) per alimentare qualunque scheda Arduino e uno step-down DC-DC con uscita variabile che utilizza un LM2596, in grado di supportare correnti molto più elevate.

Attenzione: i condensatori che vedete in foto non sono collegati al circuito.

3 di 17 | 01/05/2025, 22:47

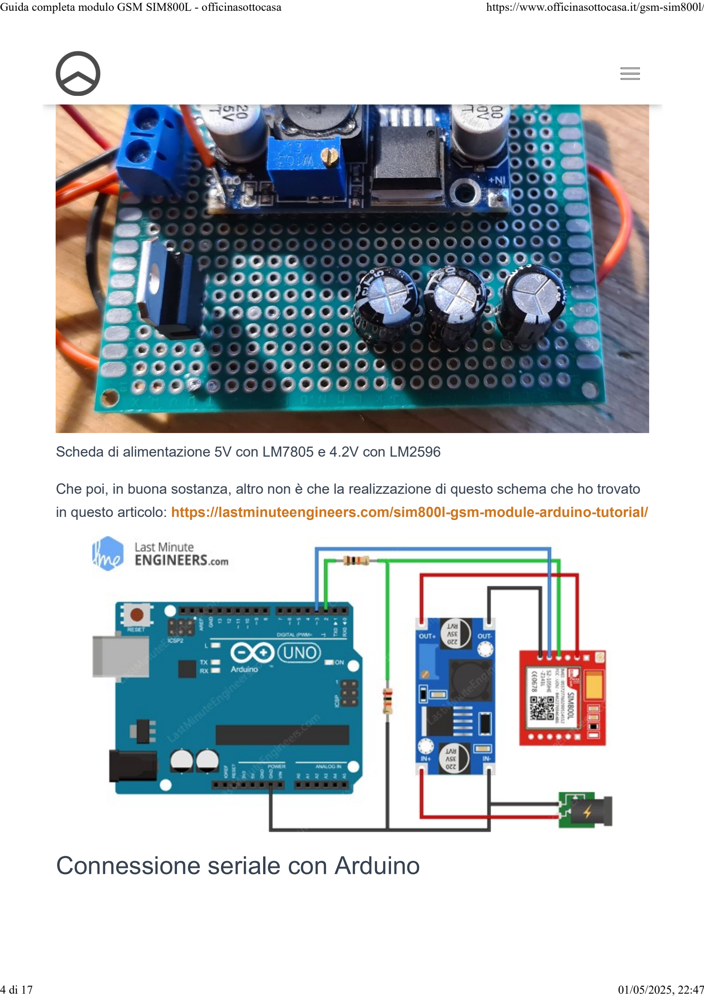
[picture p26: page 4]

Che poi, in buona sostanza, altro non è che la realizzazione di questo schema che ho trovato in questo articolo: https://lastminuteengineers.com/sim800l-gsm-module-arduino-tutorial/

# Connessione seriale con Arduino

Scheda di alimentazione 5V con LM7805 e 4.2V con LM2596

4 di 17 | 01/05/2025, 22:47

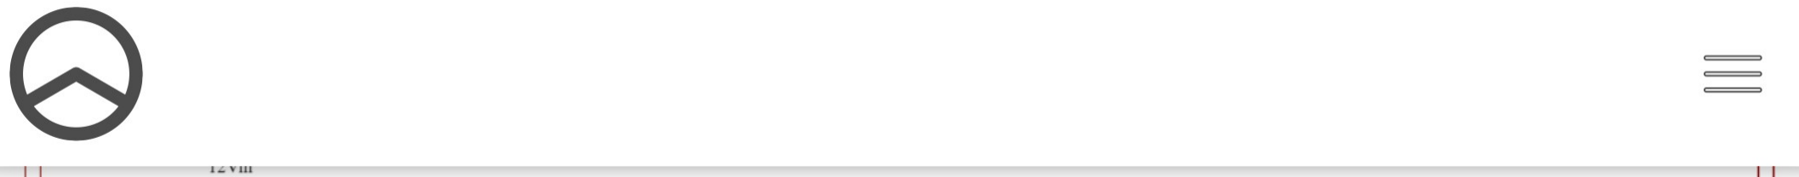
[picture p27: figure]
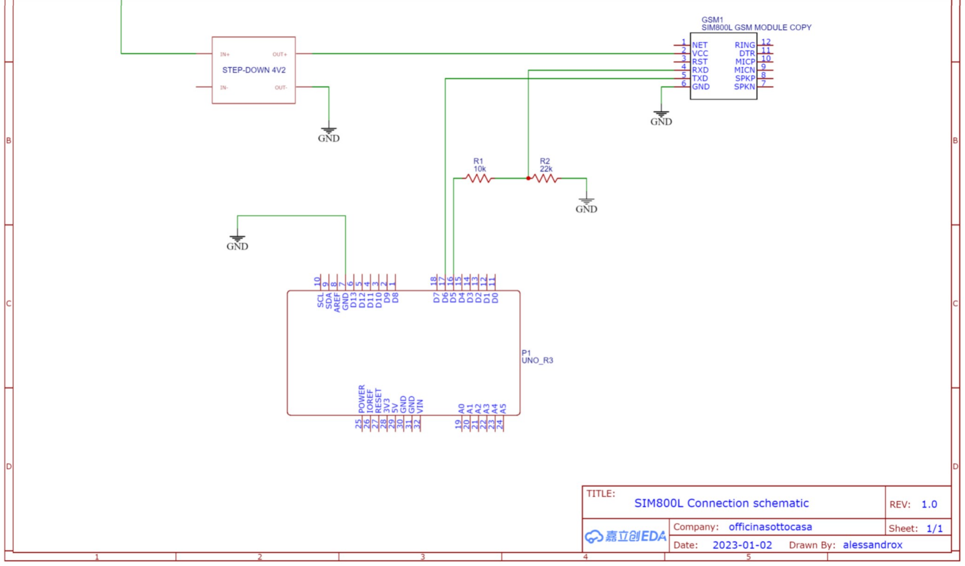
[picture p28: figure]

Iniziamo con una piccola nota sulla scheda Elegoo UNO R3, clone della omologa Arduino UNO R3.

Ha lo stesso integrato dell’originale Arduino ATMEGA328P. Tuttavia, il convertitore USB – Seriale utilizza i chip CH340G e i driver per questo Chip non sono compresi nell’installazione dell’IDE di Arduino. Motivo per cui dovranno essere installati separatamente. In questo articolo https://www.makerslab.it/installare-i-driver-per-il-modulo-ftdi-ch340g-per-i-cloni-diarduino/ trovate le informazioni e i link per scaricare e installare i driver per il CH340G.

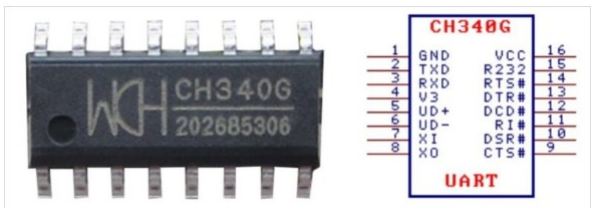
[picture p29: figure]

A questo punto dobbiamo aprire un inciso sui livelli logici che non sono gli stessi tra la scheda

Schema di connessione SIM800L e Arduino UNO R3

Convertitore USB-Seriale cloni Arduino

5 di 17 | 01/05/2025, 22:47

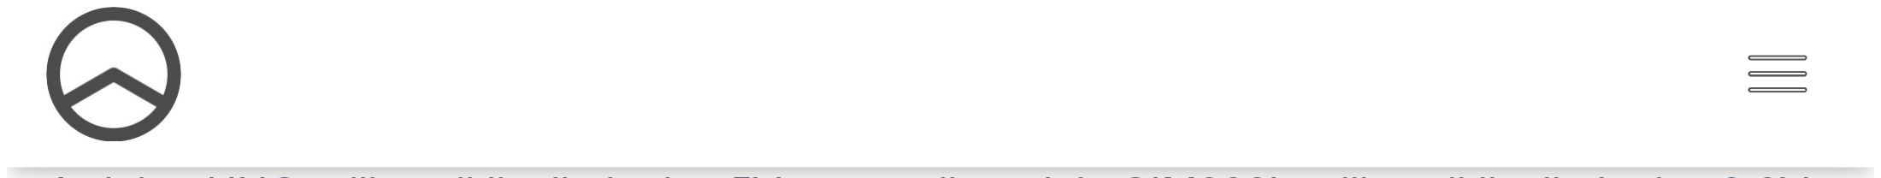
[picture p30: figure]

di controllo e il nostro modulo SIM800L.

Non possiamo collegare il pin Rx del modulo direttamente al pin digitale di Arduino perché Arduino UNO utilizza il livello logico 5V mentre il modulo SIM800L utilizza il livello logico 3.3V.

Per abbassare il livello del segnale di Arduino da 5V a 3.3V possiamo utilizzare il nostro (ormai caro e inseparabile) partitore di tensione con una resistenza da 10K tra il pin Rx di SIM800L e il pin digitale di Arduino e una da 20K tra il pin Rx e GND di SIM800L. Esistono anche dei convertitori di livello logico 5V-3V3, vi ho messo l’articolo nella sezione componenti.

# Sketch per utilizzo

A questo punto non ci resta che caricare sulla nostra scheda UNO lo sketch per permetterci di colloquiare con il SIM800L e fare i nostri esperimenti.

Io ho utilizzato un semplice sketch che invia al modulo GSM quello che noi scriviamo sul monitor seriale e visualizza sul monitor seriale quello che il modulo GSM invia alla scheda.

//Includiamo la libreria per la comunicazione seriale tra l'Arduino e il SIM800L
#include "SoftwareSerial.h";

//Definiamo il pin dell'Arduino a cui è collegato il pin TX del Sim800L, in questo caso D6 #define SIM_TX_PIN 6
//Definiamo il pin dellì'Arduino a cui è collegato il pin TX del Sim800L, in questo caso D 5 (occhio al partitore!)
#define SIM_RX_PIN 5

//Definiamo una seriale software sui TX e RX del SIM800L
SoftwareSerial serialSIM800(SIM_TX_PIN, SIM_RX_PIN);

void setup() {
//Inizializziamo la seriale tra Arduino e il PC Serial.begin(57600);
//Inizializziamo la seriale virtuale lato sim800l serialSIM800.begin(57600);
delay(500);
}

void loop() {

//Scrivi sulla seriale Arduino-PC quello che leggi dal pin TX del SIM800L if(serialSIM800.available()){
Serial.write(serialSIM800.read());
}
//Invia al pin RX del SIM800L quello che leggi sulla seriale PC-Arduino if(Serial.available()){
serialSIM800.write(Serial.read());
}
}
6 di 17 | 01/05/2025, 22:47

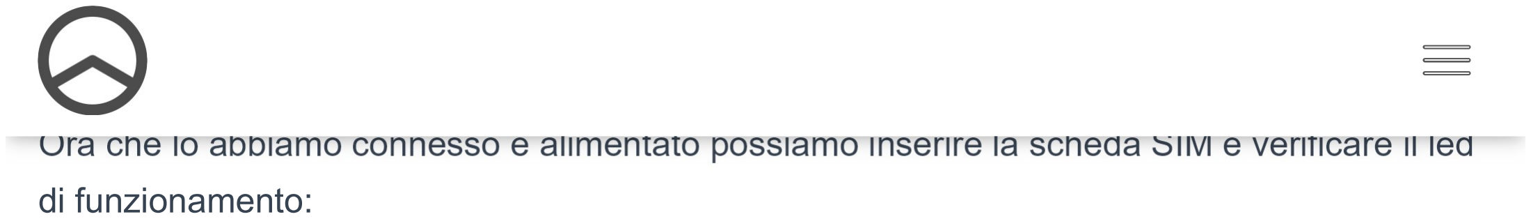
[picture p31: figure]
Indicatori di funzionamento; di funzionamento:

Ora che lo abbiamo connesso e alimentato possiamo inserire la scheda SIM e verificare il led

1 lampeggio ogni 1 secondo: modulo attivo ma non ancora registrato sulla rete;
1 lampeggio ogni 3 secondi: modulo attivo e correttamente registrato sulla rete.

Per avere maggiori dettagli sul funzionamento dobbiamo inviare qualche comando AT e analizzare le risposte.

# Comandi AT

Il manuale completo dei comandi è disponibile nella documentazione. Ne riporto qui solo alcuni, i principali, che ci permettono di testare se i collegamenti funzionano e se possiamo quindi utilizzare il nostro modulo per inviare messaggi.

Io li ho lanciati in sequenza per riepilogare i risultati e commentarli insieme.

10:40:20.795 -> AT
10:40:20.796 -> OK

Primo comando da lanciare per verificare il dialogo tra l’Arduino e il SIM800L. Se non ricevete in risposta la stringa “OK” c’è un problema nei collegamenti tra i pin RX e TX del SIM800L e i pin dell’Arduino.

10:40:25.735 -> AT+CSQ
10:40:35.980 -> +CSQ: 16,0

Serve per verificare la qualità del segnale. Il primo numero (16 nel mio caso) dovrebbe trovarsi tra 2 e 30 che equivale ad un segnale tra -110 e i -54 dbm.

10:40:35.983 -> AT+CCID
10:40:42.373 -> 8944502206206365147

Si tratta dell’identificativo della SIM. Lo uso per verificare che il modulo legga correttamente i

7 di 17 | 01/05/2025, 22:47

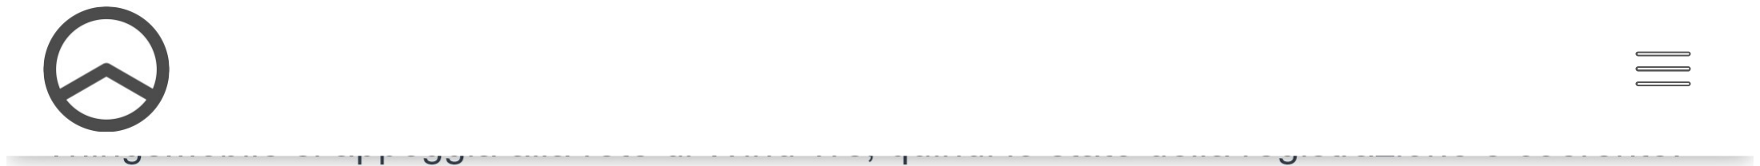
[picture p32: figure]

Verifichiamo se il modulo si è correttamente registrato sulla rete. Il secondo numero (pari a 5) indica che siamo registrati sulla rete e che siamo in roaming. Effettivamente il nostro operatore ThingsMobile si appoggia alla rete di Wind Tre, quindi lo stato della registrazione è coerente.

10:40:50.949 -> AT+COPS?
10:40:57.062 -> +COPS: 0,0,"Wind Telecom SpA"
10:40:57.065 ->
10:40:57.065 -> OK

Verifichiamo anche l’operatore con cui siamo connessi ed effettivamente troviamo conferma di quanto sopra.

# Sleep & wake-up

Ho creato due specifiche funzioni rispettivamente per mandare il modulo in sleep mode e per “svegliarlo”. Il prerequisito è sempre che il pin DTR del SIM800L sia connesso ad un pin output dell’Arduino impostato al valore HIGH.

void sim800sleepmode(){
serialSIM800.println("AT+CSCLK=2");

}

void sim800wakeup(){
digitalWrite(DTR_PIN,LOW); delay(200);
digitalWrite(DTR_PIN,HIGH); serialSIM800.println("AT"); serialSIM800.println("AT+CSCLK=0"); }

Come vedete, per mandarlo in sleep mode è sufficiente un comando AT (AT+CSCLK=2) con pin DTR impostato ad HIGH. Il problema è che una volta entrato in sleep mode il modulo chiude le comunicazioni sulla seriale.

Per svegliarlo dalla modalità sleep è necessario mandare il pin DTR al valore LOW (io ho impostato 200 millisecondi) e a quel punto inviare un comando AT qualsiasi. Solo dopo queste operazioni si può inviare il comando AT+CSCLK=1 per ripristinare la normale funzionalità.

# Inviare un SMS

Per inviare un sms possiamo usare lo sketch di interfaccia seriale scrivendo i comandi direttamente nel monitor seriale oppure scrivere lo sketch che invia un SMS.

8 di 17 | 01/05/2025, 22:47

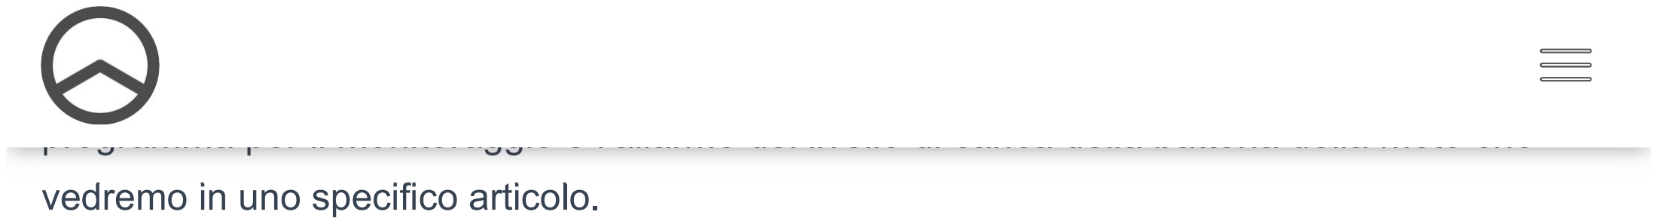
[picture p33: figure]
vedremo in uno specifico articolo.

Io ho utilizzato la prima soluzione per eseguire i test. Dopo essermi accertato che tutto funziona correttamente, inserirò le righe di comando per l’invio del messaggio all’interno del programma per il monitoraggio e l’allarme del livello di carica della batteria della moto che

11:26:23.833 -> at+cmgf=1
11:26:30.783 -> OK
11:26:30.783 -> at+cmgs="+39xxxxxxxxxx" 11:26:46.372 -> > testo di prova 11:26:53.794 -> >
11:26:58.901 -> >
11:27:12.546 -> +CMGS: 12
11:27:12.550 ->
11:27:12.550 -> OK

# Documentazione

Fondamentale la consultazione della documentazione relativa al modulo e ai comandi AT che vi condivido qui:

Datasheet SIM800L – File pdf con tutte le specifiche hardware;
Manuale comandi AT – file pdf con tutti i comandi AT, linguaggio per poter colloquiare con il modulo.

# Unisciti alla nostra community e aiutaci a crescere!

Ti è piaciuto questo articolo? Condividi la tua opinione lasciando un commento! Aiutaci a migliorare sempre di più i nostri contenuti.

Hai un blog o un sito web? Condividi il link nei commenti e visitiamolo insieme. Aiutiamoci a crescere a vicenda!

Hai un’idea in mente ma non sai da dove iniziare? Contattaci e raccontaci la tua storia.

## Riferimenti

Per arrivare a far funzionare ho consultato numerosi siti e ho deciso di proporvi l’intera sitografia qui di seguito:

https://www.makerslab.it/installare-i-driver-per-il-modulo-ftdi-ch340g-per-i-cloni-diarduino/ – driver per il ch340G;
https://www.treccarichi.net/2016/06/sim800l/ – nei commenti viene evidenziato il
9 di 17 | 01/05/2025, 22:47

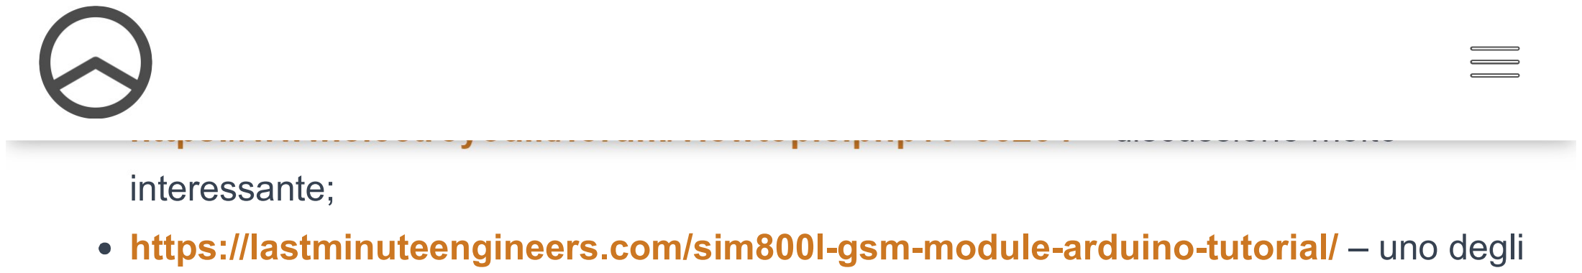
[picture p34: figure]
il prototipo; https://www.electroyou.it/forum/viewtopic.php?t=85254 – discussione molto interessante; https://lastminuteengineers.com/sim800l-gsm-module-arduino-tutorial/ – uno degli

problema relativo all’alimentazione che io stesso ho verificato in modo sperimentale con

articoli più interessanti e forse fatti meglio; https://iemma.it/blog/sim800l-modulo-gsm-gprs-per-arduino – fondamentale per la questione del partitore per l’adattamento dei livelli logici tra arduino e sim800l; https://pijaeducation.com/arduino/gsm/send-receive-messages-using-sim800lwith-arduino/
https://andino.systems/extensions/2g-modem-sim800l/smshttps://www.raviyp.com/sim900-sim800-sleep-mode-at-commands/ – articolo molto interessante er gestire lo sleep-mode e soprattutto la funzione di wake-up da software

Categorie: ELETTRONICA

Tags: Arduino sim800l

RISPONDI

RISPONDI

RISPONDI

## 6 commenti

giuseppe

ciao il modulo SIM800L funziona con tutte le sim

Alessandro

Ciao Giuseppe e grazie per il tuo contributo. Se sei interessato ad altri contenuti come questo faccelo sapere. Il vostro feedback è fondamentale per pubblicare contenuti utili e di qualità.

GIUSEPPE

Ciao mario , questo modulo sim800L funziona con le sim 4 e 5, grazie

Mario

10 di 17 | 01/05/2025, 22:47

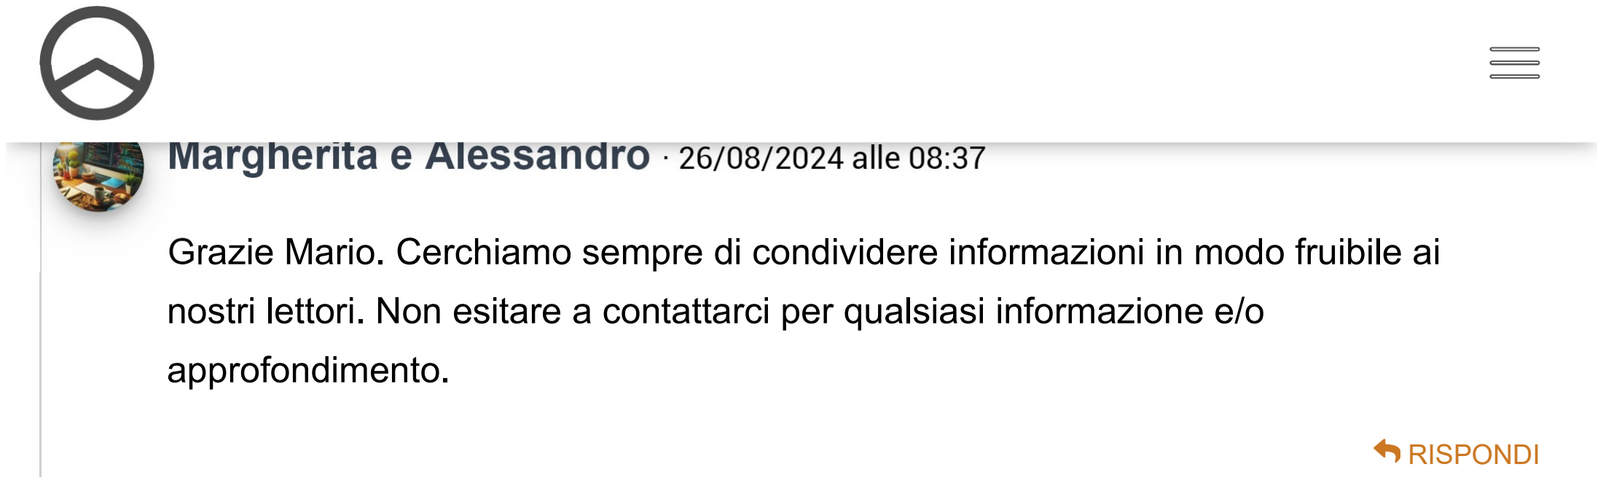
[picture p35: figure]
RISPONDI; Complimenti molto chiaro e interessante; Margherita e Alessandro; approfondimento.

RISPONDI

Grazie Mario. Cerchiamo sempre di condividere informazioni in modo fruibile ai nostri lettori. Non esitare a contattarci per qualsiasi informazione e/o

Come monitorare blackout della rete elettrica da remoto con Arduino e un SIM800L - officinasottocasa

[…] In questo articolo usiamo il nostro caro circuito SIM800L. Non ci dilungheremo sul suo funzionamento perché abbiamo già detto tutto in questo articolo: Guida completa modulo GSM SIM800L […]

## Lascia un commento

Salva il mio nome, email e sito web in questo browser per la prossima volta che commento.

Nome *

Email *

Sito web

A cosa stai pensando?

11 di 17 | 01/05/2025, 22:47

Vuoi contribuire al nostro blog? Clicca qui

Categorie

Arredo giardino (3)

Armadi da giardino (2)

Coffee table (1)

Tavoli da giardino (1)

Complementi (2)

arredo soggiorno (2)

Elettronica (6)

Ferro (12)

Lampade (2)

Lampade da terra (2)

Legno (8)

Montessori (2)

Melange (5)

Mobili (5)

Carrelli TV (1)

Consolle (1)

HI-FI (2)

Librerie (1)

Mobili TV (1)

Officina (12)

Creazioni (10)

Materiali (1)

Storie (2)

12 di 17 | 01/05/2025, 22:47

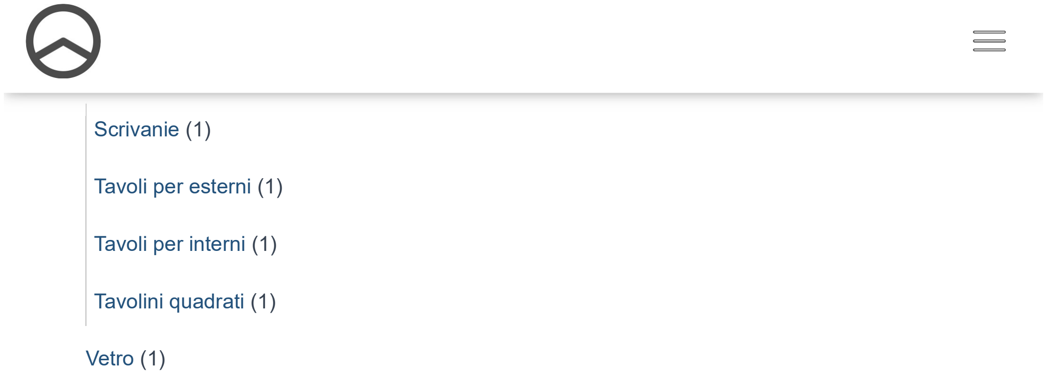
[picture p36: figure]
Progettazione 3D (1); Tavoli (3); Scrivanie (1); Tavoli per esterni (1); Tavoli per interni (1); Tavolini quadrati (1); Vetro (1)

## Articoli correlati

13 di 17 | 01/05/2025, 22:47

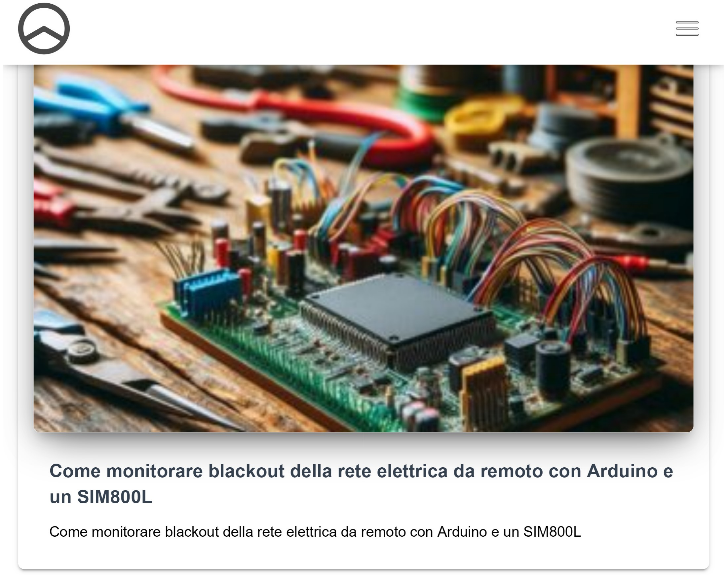
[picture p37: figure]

14 di 17 | 01/05/2025, 22:47

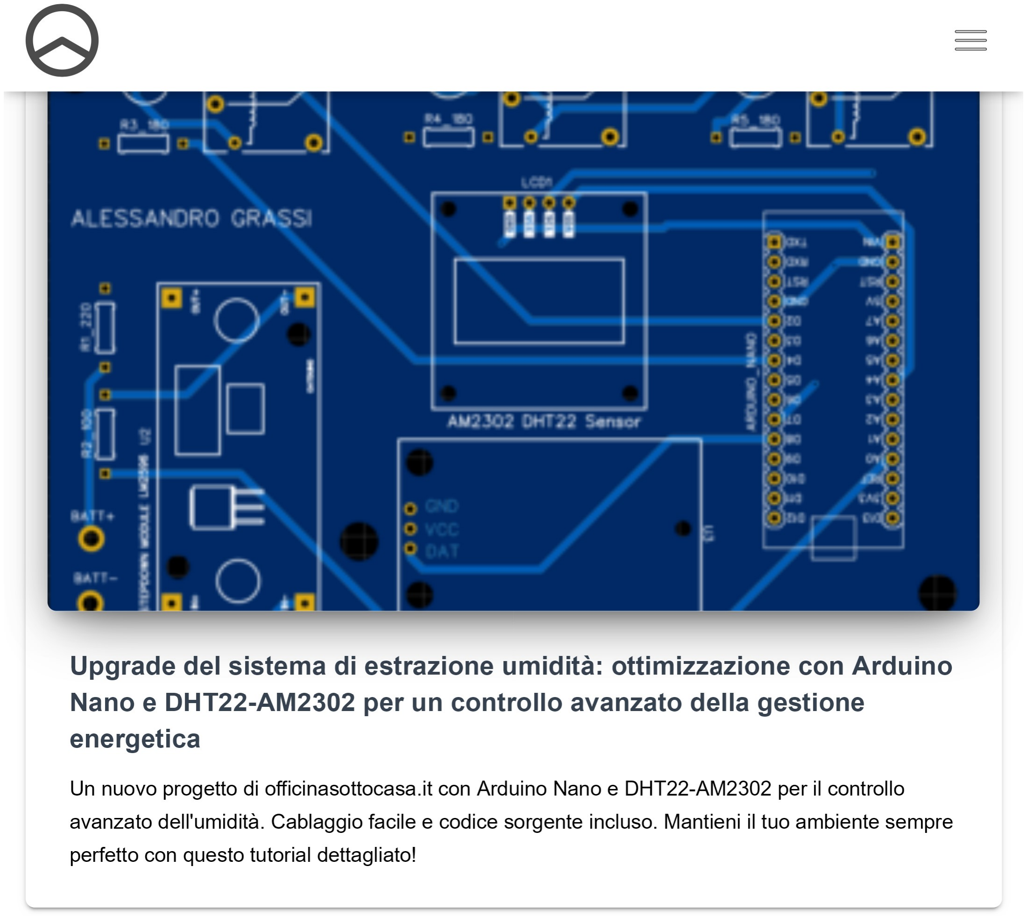
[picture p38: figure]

15 di 17 | 01/05/2025, 22:47

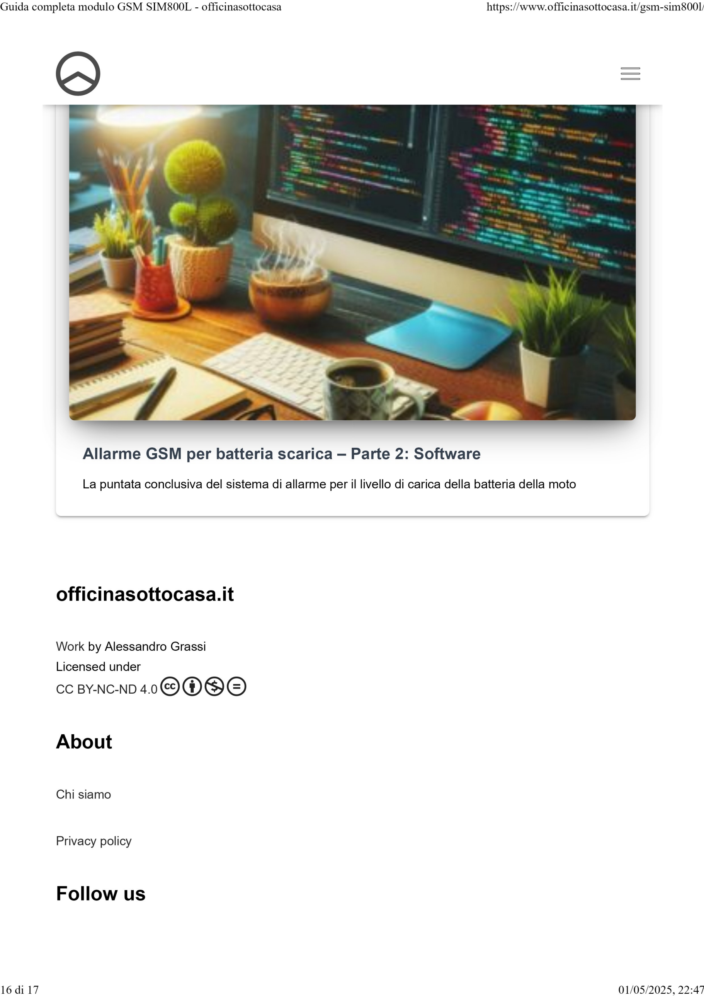
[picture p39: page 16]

## officinasottocasa.it

by Alessandro Grassi
Licensed under

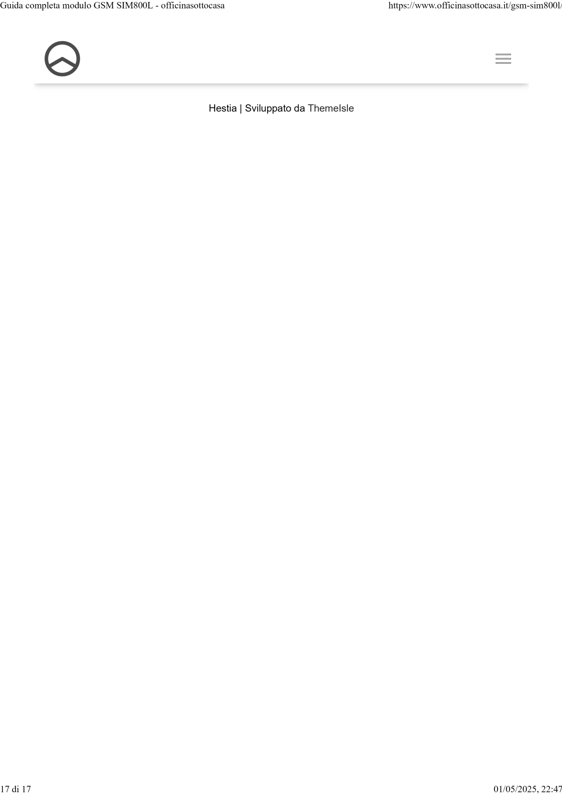
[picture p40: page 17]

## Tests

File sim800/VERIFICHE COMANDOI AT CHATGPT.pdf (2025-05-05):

Sim800 evb 8 blink

Potresti chiarire meglio cosa intendi con "SIM800 EVB 8 blink"? Le possibilità potrebbero essere:

### 1. Vuoi far lampeggiare un LED (blink) tramite un modulo SIM800

EVB collegato a un microcontrollore come Arduino?

### 2. Vuoi sapere cosa significa il lampeggio (blink) del LED "NET" sul

modulo SIM800?

### 3. Ti riferisci a un codice AT o sketch con 8 lampeggi per indicare

qualcosa?

Fammi sapere cosa vuoi ottenere esattamente, così ti guido passo per passo.

2

Perfetto, ti riferisci al LED "NET" sul modulo SIM800 EVB. Questo LED serve a indicare lo stato della connessione GSM. Il numero e la frequenza dei lampeggi ha un significato preciso. Ecco cosa significano i diversi comportamenti:

### Significato dei lampeggi del LED NET su SIM800:

Spento: Il modulo è spento o non funziona correttamente. Lampeggia ogni 1 secondo: Il modulo è acceso ma non registrato

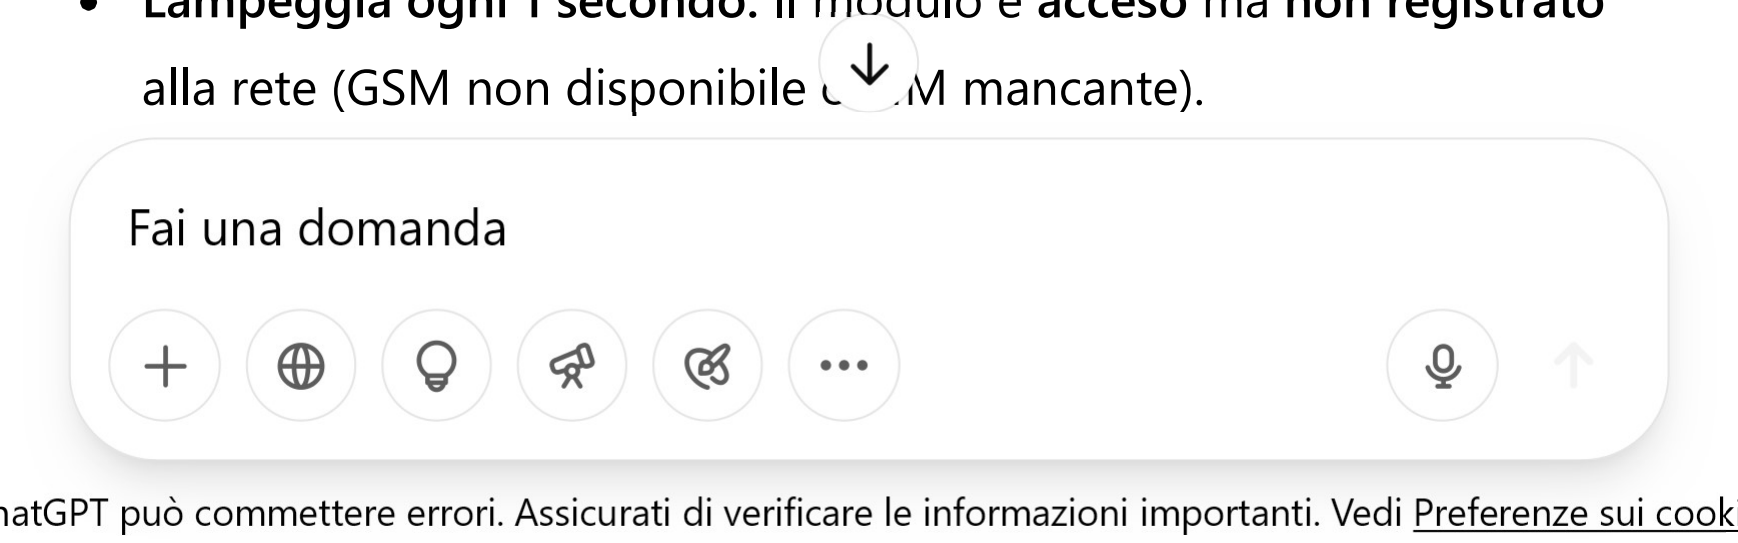
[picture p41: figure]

alla rete (GSM non disponibile o SIM mancante).
Lampeggia ogni 2 secondi: Il modulo è registrato alla rete GSM

ChatGPT può commettere errori. Assicurati di verificare le informazioni importanti. Vedi Preferenze sui cookie.

SIM800 EVB Blink LED | https://chatgpt.com/c/6816a79c-4614-800d-851e-a7fbf5f262b9
1 di 1 | 04/05/2025, 17:13

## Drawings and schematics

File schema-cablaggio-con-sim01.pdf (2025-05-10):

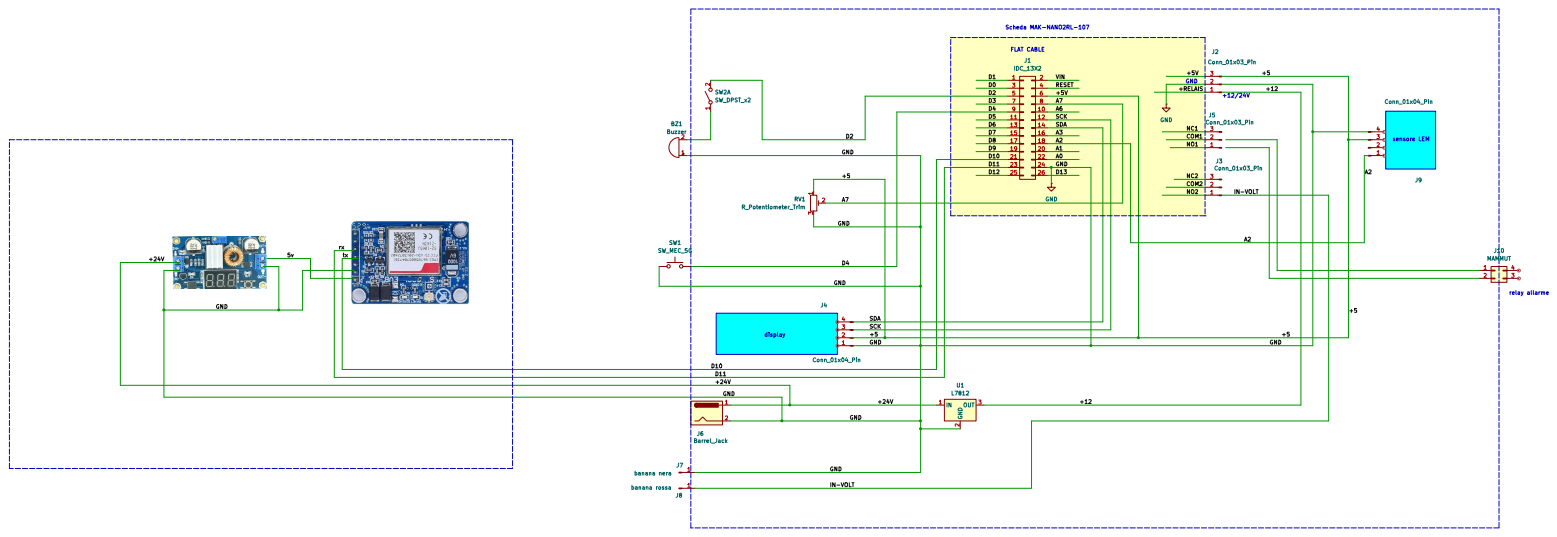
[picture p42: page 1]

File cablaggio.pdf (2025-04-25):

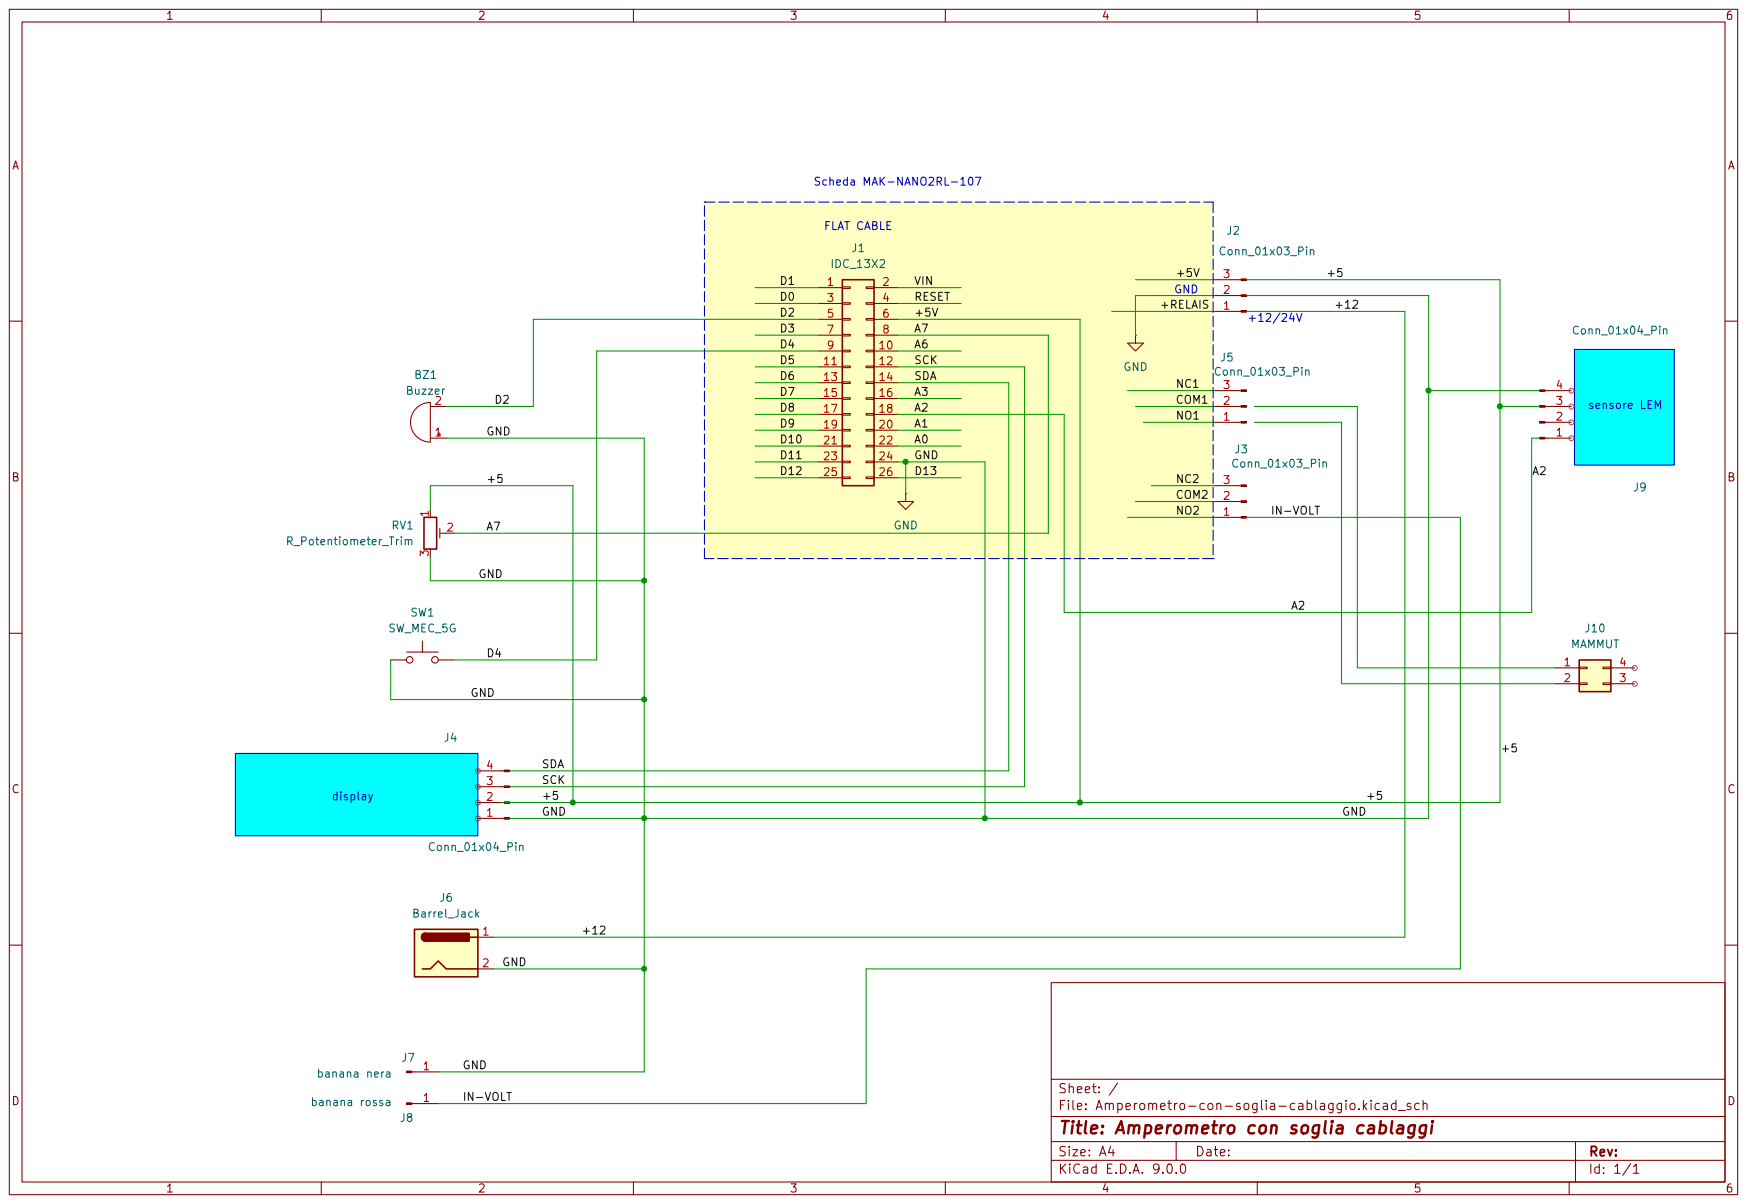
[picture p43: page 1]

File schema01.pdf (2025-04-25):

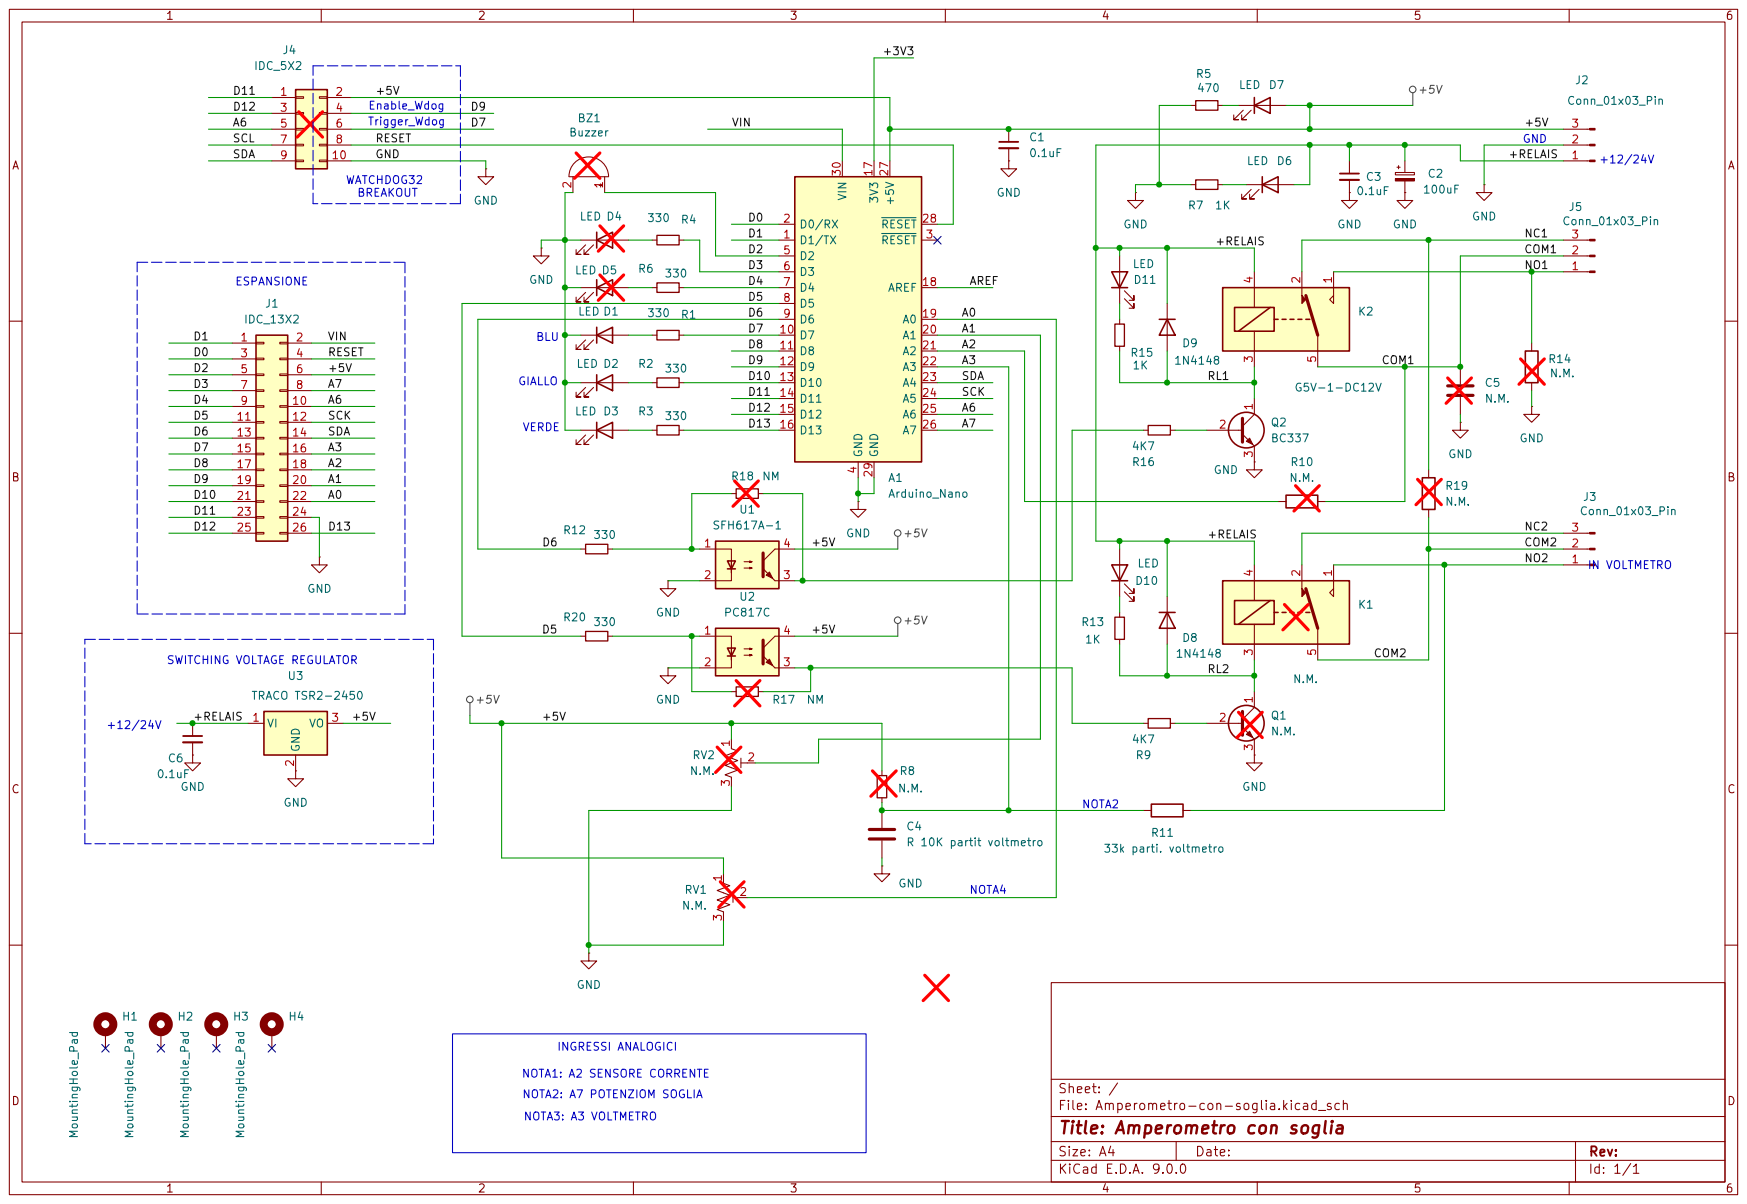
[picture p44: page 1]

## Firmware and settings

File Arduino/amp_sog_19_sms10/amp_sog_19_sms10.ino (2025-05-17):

String Versione = "amp_sog_19_sms10";
/*
SMS partono solo con pc connesso alla USB, ritardo partenza Serial.Software*/
#include <Wire.h>
#include "LiquidCrystal_I2C.h"
#include <EEPROM.h>
#include <SoftwareSerial.h>

SoftwareSerial sim800(9, 11); // RX, TX
// Imposta l'indirizzo I2C del modulo (generalmente 0x27 o 0x3F)
LiquidCrystal_I2C lcd(0x27, 16, 2);

//********************************************************************************************
// PIN di accesso via SMS
#define PinUtente1 "User1"
#define PinUtente2 "User2"
#define PinDati    "Statoattuale"
#define PinReset   "Resetsystem"
#define DeleteUtente2 "eleteuser2"

//********************************************************************************************
// EEPROM indirizzi Numeri telefonici UTENTE1 UTENTE2 in EEPROM
#define EEPROM_ADDR_NUM1 0
#define EEPROM_ADDR_NUM2 20
// Indirizzo EEPROM per il contatore SMS
const int addrContaSms = 40; // Scegli un indirizzo che non si sovrapponga agli altri
bool PrimoSmsDaTrasmettere = true; // appena viene trasmesso il primo sms di allarme si mette false
//********************************************************************************************
bool SimulaSensCurrPotenziom = false; //se true usa i valori del potenziometro al posto di quello dei sensori
bool LcdPresent = true; //se presente lcd
bool SimulaTensionePotenziom = false; //se true usa lettura potenziometro al posto della tensione

bool StampaOgniSecondoAbilitata = false;
//********************************************************************************************

// Numeri registrati
String numero1 = "+393333333333";
String numero2 = "+393477777777";

// Variabili per il messaggio
char msgdati[100];
int ContaSMS = 3;
char StrSogliaMilliampere[5] = "1500";
char strContaSecondiCorrenteElevata[5] = "0123";
char strCurrent[6] = "0250";
char strVoltage[5] = "12.5";
unsigned int ContaSecondi = 0;

float floatVoltage;
int intCurrent;
int intSogliaMilliampere;
unsigned int ContaSecondiCorrenteElevata = 0;
// Timer per ContaSecondi
unsigned long ultimoMillis = 0;
//const unsigned long intervalloSecondi = 1000;
#define intervalloSecondi 1000




int buttonState = 0;  // variable for reading the pushbutton status
bool BuzzerIsDisabled = false;  // se vale True il buzzer non suona
//********************************************************************************************
//Un potenziometro connesso all'ADC stabilisce il valore in milliAmpere di soglia
//Taratura rispetto all'Hardware
//const int ValoreAdcSoglia1ampere = 0x03ff;  // Valore Adc Corrente Positiva 1 ampere, da tarare per interpolazione lineare
//const int ValoreAdcSoglia0ampere = 0x0;     // Valore Adc Corrente 0 Ampere, da tarare
#define ValoreAdcSoglia1ampere 0x03ff
  // Valore Adc Corrente Positiva 1 ampere, da tarare per interpolazione lineare
#define ValoreAdcSoglia0ampere 0x0
     // Valore Adc Corrente 0 Ampere, da tarare

unsigned int adcValue ; //  valore dall'ADC


//********************************************************************************************
//Pinout di Arduino
#define Buzzer 2 // cicalino
#define buttonPin 4 //
#define Rele_Buzzer 5
#define Rele_Contatto 6

#define Led_Verde 13
#define Led_Giallo 10
#define Led_Blu 7
#define Led_Bianco 12

#define AdcSensorCurrent A2
#define AdcVoltageBattery A3
#define AdcPotenziometro A7

// Definizione delle frequenze per le note (in Hz)
#define NOTE_DO 523  // Do - 523 Hz
#define NOTE_RE 587  // Re - 587 Hz
#define NOTE_MI 659  // Mi - 659 Hz
#define NOTE_FA 698  // Fa - 698 Hz
#define NOTE_SOL 784 // Sol - 784 Hz
#define NOTE_LA 880 // Sol - 784 Hz
#define NOTE_WAIT 1200 //

int noteDuration = 500; //durata delle note
//********************************************************************************************

//*******************************************************
void WelcomeDisplay(){
    if (LcdPresent){
      lcd.setCursor(0, 0); // Posiziona il cursore sulla seconda riga, prima colonna
      lcd.print("Welcome ");

      lcd.setCursor(0, 1); // Posiziona il cursore sulla seconda riga, prima colonna
      lcd.print(Versione);
    }
}

//************************
//xxxxxxxxxxxxxxxxxxxxxxxxxxxxxxxxxxxxxxxxxxxxxxxxxxxxxxxxxxxxxxxxxxx

// Funzioni per la gestione del contatore SMS in EEPROM
void writeContaSmsEEPROM(int value) {
  EEPROM.put(addrContaSms, value);
  Serial.print(F("Scritto in EEPROM ContaSmsEEprom indirizzo "));
  Serial.print(addrContaSms);
  Serial.print(F(" Valore "));
  Serial.println(value);

}
//xxxxxxxxxxxxxxxxxxxxxxxxxxxxxxxxxxxxxxxxxxxxxxxxxxxxxxxxxxxxxxxxxxx
int readContaSmsEEPROM() {
  int value;
  EEPROM.get(addrContaSms, value);

  Serial.print(F("Letto da EEPROM ContaSmsEEprom indirizzo "));
  Serial.print(addrContaSms);
  Serial.print("");
  Serial.print(F(" Valore "));
  Serial.println(value);
  return value;
}

//---------------------------------------------------------
void SirenaFranceseVeloce(){

  noteDuration=150;
  playTone(NOTE_MI, noteDuration);
  playTone(NOTE_LA, noteDuration);
  playTone(NOTE_MI, noteDuration);
  playTone(NOTE_LA, noteDuration);

  noTone(8); //fermo il tono

}

//------------------------------------


// Funzione per suonare una nota
void playTone(int frequency, int duration) {
  if (!BuzzerIsDisabled){
    tone(Buzzer, frequency, duration); // Genera il suono sul pin
    delay(duration);                      // Attendi la durata della nota
  }
  noTone(Buzzer);                    // Ferma il suono
}
//********************************
//---------------------------------------------------------
//xxxxxxxxxxxxxxxxxxxxxxxxxxxxxxxxxxxxxxxxxxxxxxxxxxxxxxxxxxxxxxxxxxx
//-----------------------------------------------

//---------------------------------------------------------
 void ProcessaPotenziometroSoglia(int valoreAdcLetto){ 
 // Il potenziometro che imposta la soglia viene letto e si calcola una corrispondente soglia in milliAmpere , da 0 a 1000
  // Calcola il valore della soglia in corrente (in milliampere) range da 0 a 1000 mA
  float FloatSogliaMilliampere = 999; // Cambia questo valore per testare
  FloatSogliaMilliampere = (valoreAdcLetto * 1000.0) / (ValoreAdcSoglia1ampere - ValoreAdcSoglia0ampere);

  // Converti il float in un intero
  intSogliaMilliampere = static_cast<int>(FloatSogliaMilliampere);

  // Usa snprintf per formattare la stringa
  snprintf(StrSogliaMilliampere, sizeof(StrSogliaMilliampere), "%4d", intSogliaMilliampere);

  // Stampa i risultati sul monitor seriale
  if (StampaOgniSecondoAbilitata){
    Serial.print(F("ADC letto (hex): 0x"));
    Serial.print(valoreAdcLetto, HEX); // Stampa il valore ADC in esadecimale

    Serial.print(F(" - Float Soglia (mA): "));
    Serial.print(FloatSogliaMilliampere); // Stampa lo scostamento in decimale

    Serial.print(F(" - int Soglia (mA): "));
    Serial.print(intSogliaMilliampere); // Stampa lo scostamento in decimale

    Serial.print(F(" - Strings Soglia (mA): "));
    Serial.println(StrSogliaMilliampere); // Stampa lo scostamento in decimale
  }
 }




//---------------------------------------------------------

void ProcessaSensoreCorrente(unsigned int adcValue){
  float currentSensor;
  // Calcola la tensione corrispondente al valore ADC

  float floatVoltageSensore = adcValue * (5.0 / 1023.0);

  // Calcola lo scostamento in bit dallo zero (2.5V)
  int deltaBit = adcValue - 512; // 512 è il valore ADC corrispondente a 2.5V
  if (StampaOgniSecondoAbilitata){
    Serial.print(F("AdcCurr="));Serial.print(adcValue);
    Serial.print(F(" - floatVoltageSensore="));Serial.print(floatVoltageSensore);   
    Serial.print(F(" - deltaBit="));Serial.print(deltaBit);
  }
  // Interpolazione lineare tra i punti dati:
  // (2.07V, -350mA) e (2.5V, 0mA)
  // (2.5V, 0mA) e (3.06V, +450mA)

  if (floatVoltageSensore <= 2.5) {
    // Calcola la corrente per valori di tensione <= 2.5V
    currentSensor = mapFloat(floatVoltageSensore, 2.07, 2.5, -350.0, 0.0);
  } else {
    // Calcola la corrente per valori di tensione > 2.5V
    currentSensor = mapFloat(floatVoltageSensore, 2.5, 3.06, 0.0, 450.0);
  }  

    // Approssima il float al numero intero più vicino
  intCurrent = static_cast<int>(round(currentSensor));
  
  // Usa snprintf per formattare la stringa
  // '%+5d' assicura che il numero sia allineato a destra con segno
  snprintf(strCurrent, sizeof(strCurrent), "%+5d", intCurrent);

  // Sostituisci il '+' con uno spazio
  /*
  if (strCurrent[0] == '+') {
    strCurrent[0] = ' ';
  }
  */

  // Stampa il risultato
  if (StampaOgniSecondoAbilitata){
    Serial.print(F(" - currentSensor="));Serial.print(currentSensor);
    Serial.print(F(" - intCurrent="));Serial.print(intCurrent);
    Serial.print(F(" - strCurrent='"));  Serial.print(strCurrent); Serial.println(F("'"));
  }



}
//----------------------------------------------
float mapFloat(float x, float in_min, float in_max, float out_min, float out_max) {
  return (x - in_min) * (out_max - out_min) / (in_max - in_min) + out_min;
}

//----------------------------------------------

void ControllaSogliaSuperata() {

  intCurrent = abs(intCurrent); // toglie il segno
  if (StampaOgniSecondoAbilitata){
    Serial.print(F("intCurrent=")); Serial.println(intCurrent);
    Serial.print(F(" - Soglia=")); Serial.println(intSogliaMilliampere);
  }

  // Controllo della corrente rispetto alla soglia
  if (intCurrent < intSogliaMilliampere) {
      if (StampaOgniSecondoAbilitata){
        Serial.println(F(" - Corrente inferiore soglia"));
      }
      // Se la corrente è inferiore alla soglia
      digitalWrite(Buzzer, LOW); // Spegne il Tone
      digitalWrite(Rele_Contatto, LOW); // Stacca il relay
      digitalWrite(Rele_Buzzer, LOW); // Stacca il relay
      noTone(Buzzer); // Spegne il Tone
      Led_giallo_off();
      Led_blu_off();
      Led_bianco_off();
      Led_verde_off();
      
  } else {
      if (StampaOgniSecondoAbilitata){
        Serial.println(F(" - Corrente SUPERIORE soglia"));
      }
      // Se la corrente è maggiore o uguale alla soglia
      digitalWrite(Rele_Contatto, HIGH); // Alimenta il relay
      digitalWrite(Rele_Buzzer, HIGH); // Alimenta il relay
      ContaSecondiCorrenteElevata++;

      //Si trasmette sms solo una volta
      if (PrimoSmsDaTrasmettere){
        PrimoSmsDaTrasmettere = false; // non se ne manderà un altro
        Led_bianco_on();
        Serial.println(F("Trasmissione primo sms in corso"));
          CostruisciMsgDati();
          sendSMS(numero1, String(msgdati));
          sendSMS(numero2, String(msgdati));
      }
      


      if (ContaSecondi % 2 == 0) {
        playTone(NOTE_MI, 500);
        //tone(Buzzer, 1000); // Suona Tone (frequenza di esempio)
        Led_giallo_on();
        Led_blu_on();
        Led_bianco_on();
        Led_verde_off();
      } else {
        playTone(NOTE_LA, 500);
        //noTone(Buzzer); // Spegne il Tone
        Led_giallo_off();
        Led_blu_off();
        Led_bianco_off();
        Led_verde_on();
      }





  } 
  





}

//---------------------------------------------------------
void ProcessaAdcTensione(unsigned int adcValue) {
  // Interpolazione lineare tra i punti dati:
  // (20 bit, 2V) e (500 bit, 12V)  floatVoltage = mapFloat2(adcValue, 20, 500, 2.0, 12.0);
  // nuovo partitore 5,05v 211bit e 12.0v 535bit
  floatVoltage = mapFloat2(adcValue, 211, 535, 5.05, 12.0);

  // Approssima il valore a una cifra decimale
  float roundedVoltage = round(floatVoltage * 10.0) / 10.0;

  // Converte il valore approssimato in una stringa temporanea
  char tempStr[6]; // Buffer temporaneo leggermente più grande per la conversione
  dtostrf(roundedVoltage, 4, 1, tempStr); // Usa 4 caratteri di larghezza, 1 cifra decimale

  // Assicurati che ci sia sempre una cifra decimale e un punto
  int len = strlen(tempStr);
  if (tempStr[len - 2] == '.') {
      // Se c'è un punto decimale seguito da uno zero, nulla da fare
      // Altrimenti, aggiungi uno zero
      if (tempStr[len - 1] == ' ') {
          tempStr[len - 1] = '0';
      }
  }

  // Copia la stringa nel buffer finale allineata a destra
  snprintf(strVoltage, 5, "%4s", tempStr);

  if (StampaOgniSecondoAbilitata){
    Serial.print(F("adcValue=")); Serial.print(adcValue);
    Serial.print(F(" - floatVoltage=")); Serial.print(floatVoltage);
    Serial.print(F(" - roundedVoltage=")); Serial.print(roundedVoltage);
    Serial.print(F(" - strVoltage=")); Serial.print(strVoltage);
    Serial.println();
  }

  

}


//------------------------------------------------------------------------------


//-----------------------------------------------






//-----------------------------------------------
void Azione7(void){

  //prova la funzione di conversione della tensione 
  for (int i =0 ; i<1024;i++){
    i=i+16;
    //ProcessaSensore(i);
    adcValue = i;
    ProcessaAdcTensione(adcValue);
  } 
}
//-----------------------------------------------

void Azione8(void){

}
//-----------------------------------------------


void Azione9(void){


}
//-----------------------------------------------

void Azione10(void){
  //legge l'AD connesso al ptenziometro


}
//-----------------------------------------------

//----------------------
void Buzzer_on(){
  digitalWrite(Buzzer, HIGH); // 4
}  

void Buzzer_off(){
  digitalWrite(Buzzer, LOW); // 4
}  
//---------------
void Led_giallo_on(){
  digitalWrite(Led_Giallo, HIGH); // 4
}  

void Led_giallo_off(){
  digitalWrite(Led_Giallo, LOW); // 4
}
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
void loop() {
  
/*
void LetturaAnalogiche(){
  Azione4(); //soglia potenziometro
  Azione6(); //legge corrente sensore
  Azione8(); //legge tensione batteria
  Azione9(); //legge button, se premuto azzera ContaSecondiCorrenteElevata
  Azione10(); //compara corrente sensore con soglia potenziometro
  Serial.print(" - ContaSecondiCorrenteElevata= ");Serial.println(ContaSecondiCorrenteElevata);
}
*/
  LetturaAnalogiche();
  // Incrementa ContaSecondi ogni secondo
  if (millis() - ultimoMillis >= intervalloSecondi) {
    ultimoMillis = millis();
    ContaSecondi++;
    StampaOgniSecondoAbilitata = true; //abilita le stampe di debug, ma solo ogni secondo
    
    Serial.println();
    Serial.println(ContaSecondi);
    if (ContaSecondi % 50 == 0) {
      //va acapo per non sforare con il terminale
      Serial.println();
    }
  }

  // Controllo SMS
  if (sim800.available()) {
    Led_bianco_on();
    String raw = sim800.readString();
    raw.trim();
    Serial.print(F("raw: >")); Serial.print(raw);Serial.println(F("<"));

    if (raw.indexOf("+CMT:") != -1) {
      int msgStart = raw.indexOf("\n", raw.indexOf("\n") + 1);
      Serial.print(F("msgStart: "));Serial.println(msgStart);
      String contenuto = "";
      if (msgStart != -1) {
          contenuto = raw.substring(msgStart);
          contenuto.trim(); // ✅ CORRETTO
          Serial.print(F("contenuto: ")); Serial.println(contenuto);
      }

      int index = raw.indexOf("+39");
      if (index != -1) {
        String numero = raw.substring(index, index + 13);
        Serial.print(F("numero: ")); Serial.println(numero);
        Serial.print(F("raw2: >")); Serial.print(raw);Serial.println(F("<"));


        String TempString ="xxxxx";

        TempString = PinUtente1;
        if (raw.indexOf(TempString) != -1) {
          Serial.println(F("Match PinUtente1="));
          numero1 = numero;
          writeStringToEEPROM(EEPROM_ADDR_NUM1, numero1);
          sendSMS(numero1, "Utente1 registrato correttamente.");
        }

        TempString = PinUtente2;
        if (raw.indexOf(TempString) != -1) {
          Serial.println(F("Match PinUtente2"));
          numero2 = numero;
          writeStringToEEPROM(EEPROM_ADDR_NUM2, numero2);
          sendSMS(numero2, "Utente2 registrato correttamente.");
        }

        TempString = DeleteUtente2;
        if (raw.indexOf(TempString) != -1) {
          Serial.println(F("Match DeleteUtente2"));
          numero2 = "+39";
          writeStringToEEPROM(EEPROM_ADDR_NUM2, numero2);
          sendSMS(numero1, "Utente2 cancellato correttamente.");
        }

        TempString = PinDati;
        if (raw.indexOf(TempString) != -1) {
          Serial.println(F("Match PinDati"));
          CostruisciMsgDati();
          sendSMS(numero, String(msgdati));
        }

        TempString = PinReset;
        if (raw.indexOf(TempString) != -1) {
            Serial.println(F("Match PinReset"));
            sendSMS(numero1, "Reset in corso...");
            delay(1000);
            sim800.println("AT+CFUN=1,1");
            delay(1000);
            resetCPU();         
        }
      }
    }
  }
  Led_bianco_off();
}

// Crea msgdati con tutte le variabili
void CostruisciMsgDati() {
  snprintf(msgdati, sizeof(msgdati),
           "SMS:%d | Soglia:%smA | Current:%smA | Time.alarm:%s | Volt:%s | Time.tot:%u",
           ContaSMS,
           StrSogliaMilliampere,
           strCurrent,
           strContaSecondiCorrenteElevata,
           strVoltage,
           ContaSecondi);
}

// Invia SMS
void sendSMS(String numero, String messaggio) {
  Led_bianco_on();
  sim800.println("AT+CMGS=\"" + numero + "\"");
  delay(1000);
  sim800.print(messaggio);
  sim800.write(26); // Ctrl+Z
  delay(3000);
  Led_bianco_off();

  // Verifica invio
  unsigned long tempoInizio = millis();
  String risposta = "";
  while (millis() - tempoInizio < 5000) {
    if (sim800.available()) {
      char c = sim800.read();
      risposta += c;
      if (risposta.indexOf("+CMGS:") != -1) {
        Serial.print(F("SMS inviato con successo a "));
        Serial.println(numero);
        return;
      }
    }
  }
  Serial.print(F("ERRORE: invio SMS fallito verso "));
  Serial.println(numero);

}

// EEPROM - scrittura
void writeStringToEEPROM(int addr, String data) {
  for (int i = 0; i < data.length(); i++) {
    EEPROM.write(addr + i, data[i]);
  }
  EEPROM.write(addr + data.length(), '\0');
}

// EEPROM - lettura
String readStringFromEEPROM(int addr) {
  char data[20];
  int len = 0;
  unsigned char k = EEPROM.read(addr);
  while (k != '\0' && len < 19) {
    data[len++] = k;
    k = EEPROM.read(addr + len);
  }
  data[len] = '\0';
  return String(data);
}

// Reset software della CPU
void resetCPU() {
  void(* Riavvia)(void) = 0;
  Riavvia();
}

//*******************************************************************************
void LetturaAnalogiche(){

//**********
  //Azione4(); //soglia potenziometro
  //usa la funzione  ProcessaPotenziometroSoglia

  //legge l'AD connesso al ptenziometro
  int valoreAnalogico = analogRead(AdcPotenziometro);

  // lo converte
  ProcessaPotenziometroSoglia(valoreAnalogico);

  // lo manda al display LCD riga 1 posizione 12
  if (LcdPresent){
  
    lcd.setCursor(8, 0); // Posiziona il cursore sulla prima riga, colonna 1
    lcd.print(" SmA");

    lcd.setCursor(12, 0); // Posiziona il cursore sulla prima riga, colonna 1
    lcd.print(StrSogliaMilliampere);

  }
//**********
  //Azione6(); //legge corrente sensore
/*
  #define AdcSensorCurrent A2
  #define AdcVoltageBattery A3
  #define AdcPotenziometro A7
*/
  if(SimulaSensCurrPotenziom){
    //in debug legge l'AD connesso al potenziometro
    adcValue = analogRead(AdcPotenziometro);
  } else {
    //run time legge l'AD connesso al sensore corrente
    adcValue = analogRead(AdcSensorCurrent);    
  }

  ProcessaSensoreCorrente(adcValue);

  // lo manda al display LCD riga 1 posizione 12
  if (LcdPresent){
    lcd.setCursor(0, 0); // Posiziona il cursore sulla prima riga, colonna 1
    lcd.print("ImA=");

    lcd.setCursor(3, 0); // Posiziona il cursore sulla prima riga, colonna 1
    lcd.print(strCurrent);
  }  
//**********  
  //Azione8(); //legge tensione batteria
/*
  #define AdcSensorCurrent A2
  #define AdcVoltageBattery A3
  #define AdcPotenziometro A7
*/

  if(SimulaTensionePotenziom){
    //in SimulaTensionePotenziom legge l'AD connesso al potenziometro
    adcValue = analogRead(AdcPotenziometro);
  } else {
    //run time legge l'AD connesso al sensore tensione
    adcValue = analogRead(AdcVoltageBattery);    
  }

  ProcessaAdcTensione(adcValue);

  // lo manda al display LCD riga 1 posizione 12
  if (LcdPresent){
    lcd.setCursor(0, 1); // Posiziona il cursore sulla prima riga, colonna 1
    lcd.print("Volt");

    lcd.setCursor(4, 1); // Posiziona il cursore sulla prima riga, colonna 1
    lcd.print(strVoltage);
  }


//**********  
  //Azione9(); //legge button, se premuto azzera ContaSecondiCorrenteElevata
  //test button
  buttonState = digitalRead(buttonPin);

  // check if the pushbutton is pressed. If it is, the buttonState is HIGH:
  if (buttonState == LOW) {
    Serial.println(F("Button premuto"));
    ContaSecondiCorrenteElevata=0;
    if (LcdPresent){
      lcd.setCursor(0, 0); // Posiziona il cursore sulla seconda riga, prima colonna
      lcd.print("RESET IN CORSO  ");

      lcd.setCursor(0, 1); // Posiziona il cursore sulla seconda riga, prima colonna
      lcd.print(Versione);
    }
    delay(1000);
    sim800.println("AT+CFUN=1,1");
    delay(2000);
    resetCPU(); 




  } else {
    // turn LED off:
    if (StampaOgniSecondoAbilitata){
      Serial.println(F("Button rilasciato"));
    }
    
  }
  

//**********  
  //Azione10(); //compara corrente sensore con soglia potenziometro
  
  ControllaSogliaSuperata();
  if(ContaSecondiCorrenteElevata>9999){
    ContaSecondiCorrenteElevata=9999; //satura a 9999
  }
  sprintf(strContaSecondiCorrenteElevata, "%04u", ContaSecondiCorrenteElevata);

  // lo manda al display LCD riga 1 posizione 12
  if (LcdPresent){
    lcd.setCursor(8, 1); // Posiziona il cursore sulla prima riga, colonna 1
    lcd.print(" Err");

    lcd.setCursor(12, 1); // Posiziona il cursore sulla prima riga, colonna 1
    lcd.print(strContaSecondiCorrenteElevata);
  }

  if (StampaOgniSecondoAbilitata){
    Serial.print(F(" - Conta_Secondi_Corrente_Elevata= "));Serial.println(ContaSecondiCorrenteElevata);
  }
  StampaOgniSecondoAbilitata = false; //questa era l'ultima stampa di debug
//**********
}

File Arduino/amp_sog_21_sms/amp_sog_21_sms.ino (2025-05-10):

String Versione = "amp-sogl-21_sms";
/*
= alla vers. amp-sogl-17 ma con librerie in locale nel progetto
Per entrare nel menu scrivere "Menu" a 115200 baud

Nota: se debug è attivo anzichè i valori reali di corrente e tensione, viene letto il potenziometro

Funzioni principali:
- Legge la corrente da un sensore LEM, nel range +/- 1000 milliAmpere
- Legge una soglia impostata su un potenziometro, nel range da 0 a 1000 milliAmprer
- Legge la tensione di batteria, nel range da 1 a 15 volt
- Una volta al secondo verifica se la corrente circolante è maggiore della soglia impostata, facendo queste cose:
  - Conta i secondi in cui la corrente supera la sogia 
  - Suona il cicalino
  - Chiude un relay

  I 4 valori (Corrente, Soglia, Tensione, Secondi over soglia)  vengono visualizzati su un display 

  Premendo il pulsante è possibile azzerare il conta secondi over soglia.

Al reset se si parte con il pulsante premuto si disablita il buzzer


*/
#include <Wire.h>
#include "LiquidCrystal_I2C.h"
#include <SoftwareSerial.h>
#include <EEPROM.h>

// SIM800L su pin 7 RX, 8 TX (adatta se usi diversi pin)
SoftwareSerial sim800(10, 11);

// Imposta l'indirizzo I2C del modulo (generalmente 0x27 o 0x3F)
LiquidCrystal_I2C lcd(0x27, 16, 2);

bool DebugOn=false; //se true usa i valori del potenziometro al posto di quello dei sensori
int buttonState = 0;  // variable for reading the pushbutton status
bool BuzzerIsDisabled = false;  // se vale True il buzzer non suona
//********************************************************************************************
//Un potenziometro connesso all'ADC stabilisce il valore in milliAmpere di soglia
//Taratura rispetto all'Hardware
const int ValoreAdcSoglia1ampere = 0x03ff;  // Valore Adc Corrente Positiva 1 ampere, da tarare per interpolazione lineare
const int ValoreAdcSoglia0ampere = 0x0;     // Valore Adc Corrente 0 Ampere, da tarare

unsigned int adcValue ; //  valore dall'ADC

float currentSensor;
bool UnSoloSms = false;




//--------------------------------------------
//Due banane connettono i due poli della batteria su auto tramite un diodo ed un partitore di tensione 33k/10k

//------------------------------------------------------------
//------------------------------------------------------------
//------------------------------------------------------------
//------------------------------------------------------------
//------------------------------------------------------------
//------------------------------------------------------------
// risultati

//

float floatVoltage;


char strVoltage[5]; // 4 caratteri + 1 per il terminatore di stringa

int intCurrent;
char strCurrent[6]; // 5 caratteri + 1 per il terminatore di stringa

int intSogliaMilliampere; 
char StrSogliaMilliampere[5]; // 4 caratteri + 1 per il terminatore di stringa

unsigned int ContaSecondi = 0;
unsigned int ContaSecondiCorrenteElevata = 0;

char strContaSecondiCorrenteElevata[5];

int ContaSMS = 1; //conta gli sms dal reset
//------------------------------------------------------------
//------------------------------------------------------------
//------------------------------------------------------------
//------------------------------------------------------------
//------------------------------------------------------------



//********************************************************************************************
//Pinout di Arduino
#define Buzzer 2 // cicalino
#define buttonPin 4 //
#define Rele_Buzzer 5
#define Rele_Contatto 6

#define Led_Verde 13
#define Led_Giallo 10
#define Led_Blu 7
#define Led_Bianco 12

#define AdcSensorCurrent A2
#define AdcVoltageBattery A3
#define AdcPotenziometro A7

// Definizione delle frequenze per le note (in Hz)
#define NOTE_DO 523  // Do - 523 Hz
#define NOTE_RE 587  // Re - 587 Hz
#define NOTE_MI 659  // Mi - 659 Hz
#define NOTE_FA 698  // Fa - 698 Hz
#define NOTE_SOL 784 // Sol - 784 Hz
#define NOTE_LA 880 // Sol - 784 Hz
#define NOTE_WAIT 1200 //

int noteDuration = 500; //durata delle note
//********************************************************************************************
// Dichiarazione della variabile per tenere traccia dello stato del pin


String inputString = "";      // a String to hold incoming data
bool stringComplete = false;  // whether the string is complete
bool ExitFromMenu = false;    // Used for exit from loop 
char Cestino;                 // 
const long interval = 1000;           // interval at which to blink (milliseconds)

bool debug = false;
String inputBuffer = "";       // Buffer per memorizzare i caratteri ricevuti

// Generally, you should use "unsigned long" for variables that hold time
// The value will quickly become too large for an int to store
unsigned long previousMillis = 0;  // will store last time LED was updated

int counter = 1000;
//------------------------------------

//PROTOTIPI
void sendSMS(String numero, String messaggioBase);
void Azione1(void);
void Azione2(void);
void Azione3(void);
void Azione4(void);
void Azione5(void);
void Azione6(void);
void Azione7(void);
void Azione8(void);
void Azione9(void);
void Azione10(void);
void Azione11(void);
void Azione12(void);
void Azione13(void);
void Azione14(void);
void Azione15(void);
void Azione16(void);
void Azione17(void);
void Azione18(void);
void Azione19(void);
void Azione20(void);
void Azione99(void);
void Menu(void);
void WelcomeDisplay();
void serialEvent(void); 



//----------------------------------------------



//----------------------------------------------

//------------------------------------


// Funzione per suonare una nota
void playTone(int frequency, int duration) {
  if (!BuzzerIsDisabled){
    tone(Buzzer, frequency, duration); // Genera il suono sul pin
    delay(duration);                      // Attendi la durata della nota
  }
  noTone(Buzzer);                    // Ferma il suono
}
//********************************
//verifica se devo entrare nel menu
void CheckIfMenu(){
  // Controlla i dati ricevuti sulla seriale
  if (Serial.available() > 0) {
    char receivedChar = Serial.read(); // Legge un carattere
    inputBuffer += receivedChar;       // Aggiunge il carattere al buffer

    // Verifica se il buffer contiene la parola "Menu"
    if (inputBuffer.endsWith("Menu")) {
      Serial.println("Comando 'Menu' rilevato! Entrando nella funzione Menu().");
      Menu(); // Chiama la funzione Menu()
      inputBuffer = ""; // Resetta il buffer
    }

    // Evita che il buffer diventi troppo lungo
    if (inputBuffer.length() > 20) {
      inputBuffer = ""; // Resetta il buffer in caso di overflow
    }
  }

}
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

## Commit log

2025-04-25 aggiornato files
    [Amperometro-con-soglia-cablaggio.kicad_sch, Amperometro-con-soglia.kicad_sch, voltmetro.xlsx]
2025-05-08 schema con sim
    [Amperometro-con-soglia-cablaggio.kicad_sch]
2025-05-17 schemi definitivi
    [Amperometro-con-soglia-cablaggio.kicad_sch]
